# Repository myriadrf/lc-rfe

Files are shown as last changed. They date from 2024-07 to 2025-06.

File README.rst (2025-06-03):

LibreCellular RF Front-End
==========================

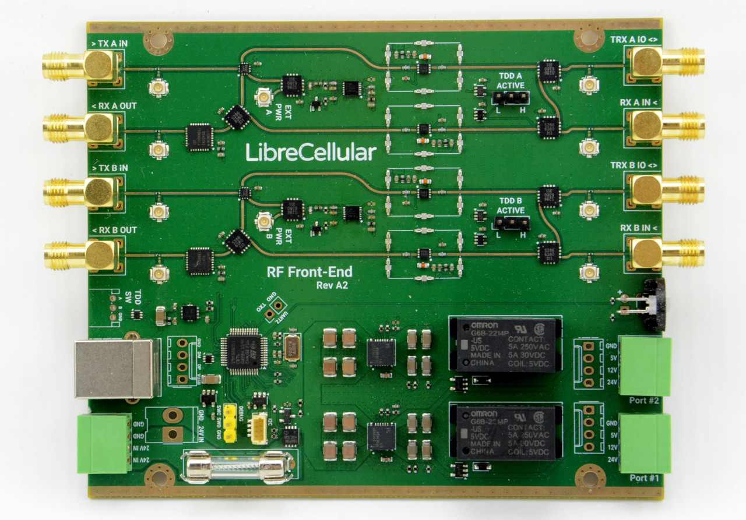
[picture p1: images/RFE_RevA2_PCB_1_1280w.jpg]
LibreCellular RFE PCBA.


This repository contains the PCB (KiCAD) design for the RF Front-End (RFE).

For further details see the `LibreCellular Documentation`_.

Licence
-------

LibreCelluar RF Front-End is copyright 2024, 2025 Ordinatra Minima Ltd & AB Open Ltd, and provided under the Solderpad Hardware License v2.1.

.. _LibreCellular Documentation: https://librecellular.org/developer/hardware/rf/rfe.html

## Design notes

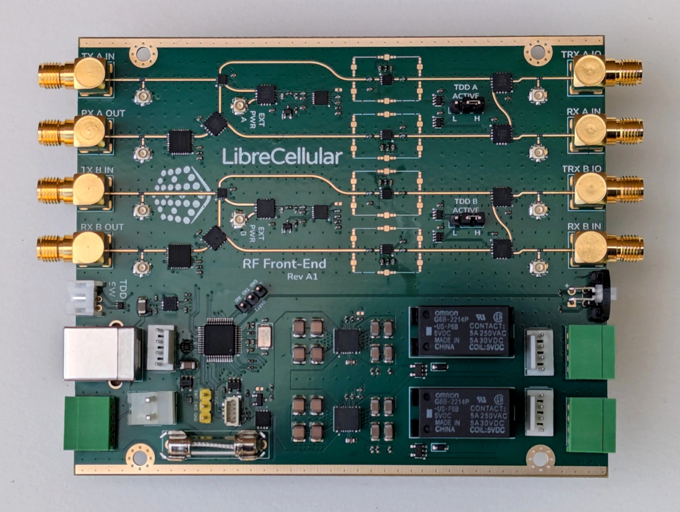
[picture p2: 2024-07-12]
images/RFE_RevA1_PCB_1_1280w.jpg

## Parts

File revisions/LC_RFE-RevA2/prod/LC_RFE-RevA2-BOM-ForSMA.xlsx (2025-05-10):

RefDes | Value | JLCASSY | Footprint
C1106,C1206,C1306,C1406 | 1000p | C1523 | Capacitor_SMD:C_0402_1005Metric
C305,C306 | 18p | C1549 | Capacitor_SMD:C_0402_1005Metric
C1104,C1204,C1304,C1404 | 27p | C1557 | Capacitor_SMD:C_0402_1005Metric
C216 | 8.2p | C1579 | Capacitor_SMD:C_0402_1005Metric
IC1504,IC1604 | SN74LVC1G32DCK | C7840 | Package_TO_SOT_SMD:SOT-353_SC-70-5
IC1503,IC1603 | SN74LVC1G04DCK | C8207 | Package_TO_SOT_SMD:SOT-353_SC-70-5
D102,D501 | USBLC6-2P6 | C15999 | LC_RFE:SOT-666
C301,C308,C603,C701,C801,C902,C1002,C1101,C1201,C1301,C1401 | 4u7 | C23733 | Capacitor_SMD:C_0402_1005Metric
R303 | 2.2K | C25879 | Resistor_SMD:R_0402_1005Metric
R304,R305 | 3.3K | C25890 | Resistor_SMD:R_0402_1005Metric
R204 | 6.98K 1% | C47500 | Resistor_SMD:R_0402_1005Metric
C1102,C1202,C1302,C1402 | 1u | C52923 | Capacitor_SMD:C_0402_1005Metric
C1103,C1203,C1303,C1403 | 100p | C77177 | Capacitor_SMD:C_0402_1005Metric
D101 | BZX84C12LT1G | C82475 | Package_TO_SOT_SMD:SOT-23
C908,C1008 | 1.8p | C85878 | Capacitor_SMD:C_0402_1005Metric
R501,R503,R505,R507,R509,R511,R513,R515 | 0 | C106227 | LC_RFE:0201-SQUARE
C906,C907,C1006,C1007 | 1n | C126493 | Capacitor_SMD:C_0402_1005Metric
D401,D402 | D_Schottky | C191023 | Diode_SMD:D_SOD-323_HandSoldering
IC401,IC402 | RT9742CGJ5 | C250546 | Package_TO_SOT_SMD:TSOT-23-5
R208 | 12.1K | C281773 | Resistor_SMD:R_0402_1005Metric
C302,C303,C304,C309,C602,C604,C702,C802,C903,C904,C905,C910,C911,C912,C1003,C1004,C1005,C1010,C1011,C1012,C1105,C1205,C1305,C1405,C1501,C1502,C1503,C1504,C1601,C1602,C1603,C1604 | 100n | C307331 | Capacitor_SMD:C_0402_1005Metric
R902,R1002 | 68 0.1% | C317908 | Resistor_SMD:R_0402_1005Metric
R105 | 75K 0.1% | C319479 | Resistor_SMD:R_0402_1005Metric
Q101 | BSZ086P03NS3G | C459171 | LC_RFE:TSDSON-8(3.3x3.3)
IC601 | Power-LDO_NCP59800BMNADJTBG | C464053 | LC_RFE:DFN-8(3x3)
C207,C208,C209,C210,C217,C218,C219,C220,C307,C601 | 22u | C478862 | Capacitor_SMD:C_1206_3216Metric
L601,L701,L801,L901,L1001,L1101,L1201,L1301,L1401 | FB | C491491 | Inductor_SMD:L_0402_1005Metric
IC302 | TPS7A0533PDBV | C493453 | Package_TO_SOT_SMD:SOT-23-5
R201 | 110K 0.1% | C517659 | Resistor_SMD:R_0402_1005Metric
C205,C215 | 1u | C519560 | Capacitor_SMD:C_0603_1608Metric
C201,C202,C203,C204,C211,C212,C213,C214 | 10u | C597578 | Capacitor_SMD:C_1210_3225Metric
IC902,IC1002 | Power-VRef_ADR5040BKSZ-REEL7 | C659592 | SOT65P210X110-3N
IC901,IC1001 | RF-PwrDet_LTC5587IDD#TRPBF | C688698 | LC_RFE:SON45P300X300X80-13N-D
R104,R106,R107,R108 | 26.1K 0.1% | C728557 | Resistor_SMD:R_0402_1005Metric
R601 | 30K9 | C852715 | Resistor_SMD:R_0402_1005Metric
R205 | 40.2K 0.1% | C852775 | Resistor_SMD:R_0402_1005Metric
IC701,IC801 | RF-Attenuator_F1956NBGI8 | C1511898 | LC_RFE:QFN50P500X500X80-33N-D
IC904,IC1004 | RF-Switch-SP3T_SKY13588-460LF | C2151906 | LC_RFE:QFN50P200X200X65-13N-D
R103 | 191K 0.1% | C2441163 | Resistor_SMD:R_0402_1005Metric
IC301 | STM32G0B1CBTx | C2847904 | Package_QFP:LQFP-48_7x7mm_P0.5mm
CON509,CON510,CON511,CON512,CON513,CON514,CON515,CON516,CON901,CON1001 | uFL | C2894919 | LC_RFE:Molex_734120110
R102,R202,R203,R206,R207,R301,R306,R401,R402,R602 | 10K | C2902636 | Resistor_SMD:R_0402_1005Metric
R302,R901,R1001 | 390 | C2906937 | Resistor_SMD:R_0402_1005Metric
Y301 | 8MHz | C3035202 | LC_RFE:Crystal_SMD_5032-2Pin_5.0x3.2mm
IC903,IC905,IC1003,IC1005 | RF-Switch-SPDT_SKY13286-359LF | C3304168 | LC_RFE:QFN65P400X400X100-17N-D
IC1501,IC1502,IC1601,IC1602 | RF-Switch_SKY13286-359LF | C3304168 | LC_RFE:QFN65P400X400X100-17N-D
L902,L1002 | 1.5nH | C3911113 | Inductor_SMD:L_0402_1005Metric
IC201,IC202 | Power-Buck_TPSM63604RDLR | C5219289 | LC_RFE:B3QFN-20(5.0x5.5)-RDL0020A
IC303 | FT24C32A-ELR-T | C5263776 | Package_TO_SOT_SMD:SOT-23-5
IC1101,IC1201,IC1301,IC1401 | RF-LNA_TQL9063 | C5346221 | LC_RFE:SON50P200X200X90-9N
L1102,L1202,L1302,L1402 | 68nH | C19191685 | Inductor_SMD:L_0603_1608Metric
MECH1101_A1, MECH1101_B1, MECH1101_C1, MECH1101_D1, MECH1101_E1, MECH1101_F1, MECH1201_A1, MECH1201_B1, MECH1201_C1, MECH1201_D1, MECH1201_E1, MECH1201_F1, MECH1301_A1, MECH1301_B1, MECH1301_C1, MECH1301_D1, MECH1301_E1, MECH1301_F1, MECH1401_A1, MECH1401_B1, MECH1401_C1, MECH1401_D1, MECH1401_E1, MECH1401_F1 | Harwin_S0941-46R | C3308740 | Harwin_S0941-46R
CON105 | BM04B-SRSS-TB | C160390 | BM04B-SRSS-TB

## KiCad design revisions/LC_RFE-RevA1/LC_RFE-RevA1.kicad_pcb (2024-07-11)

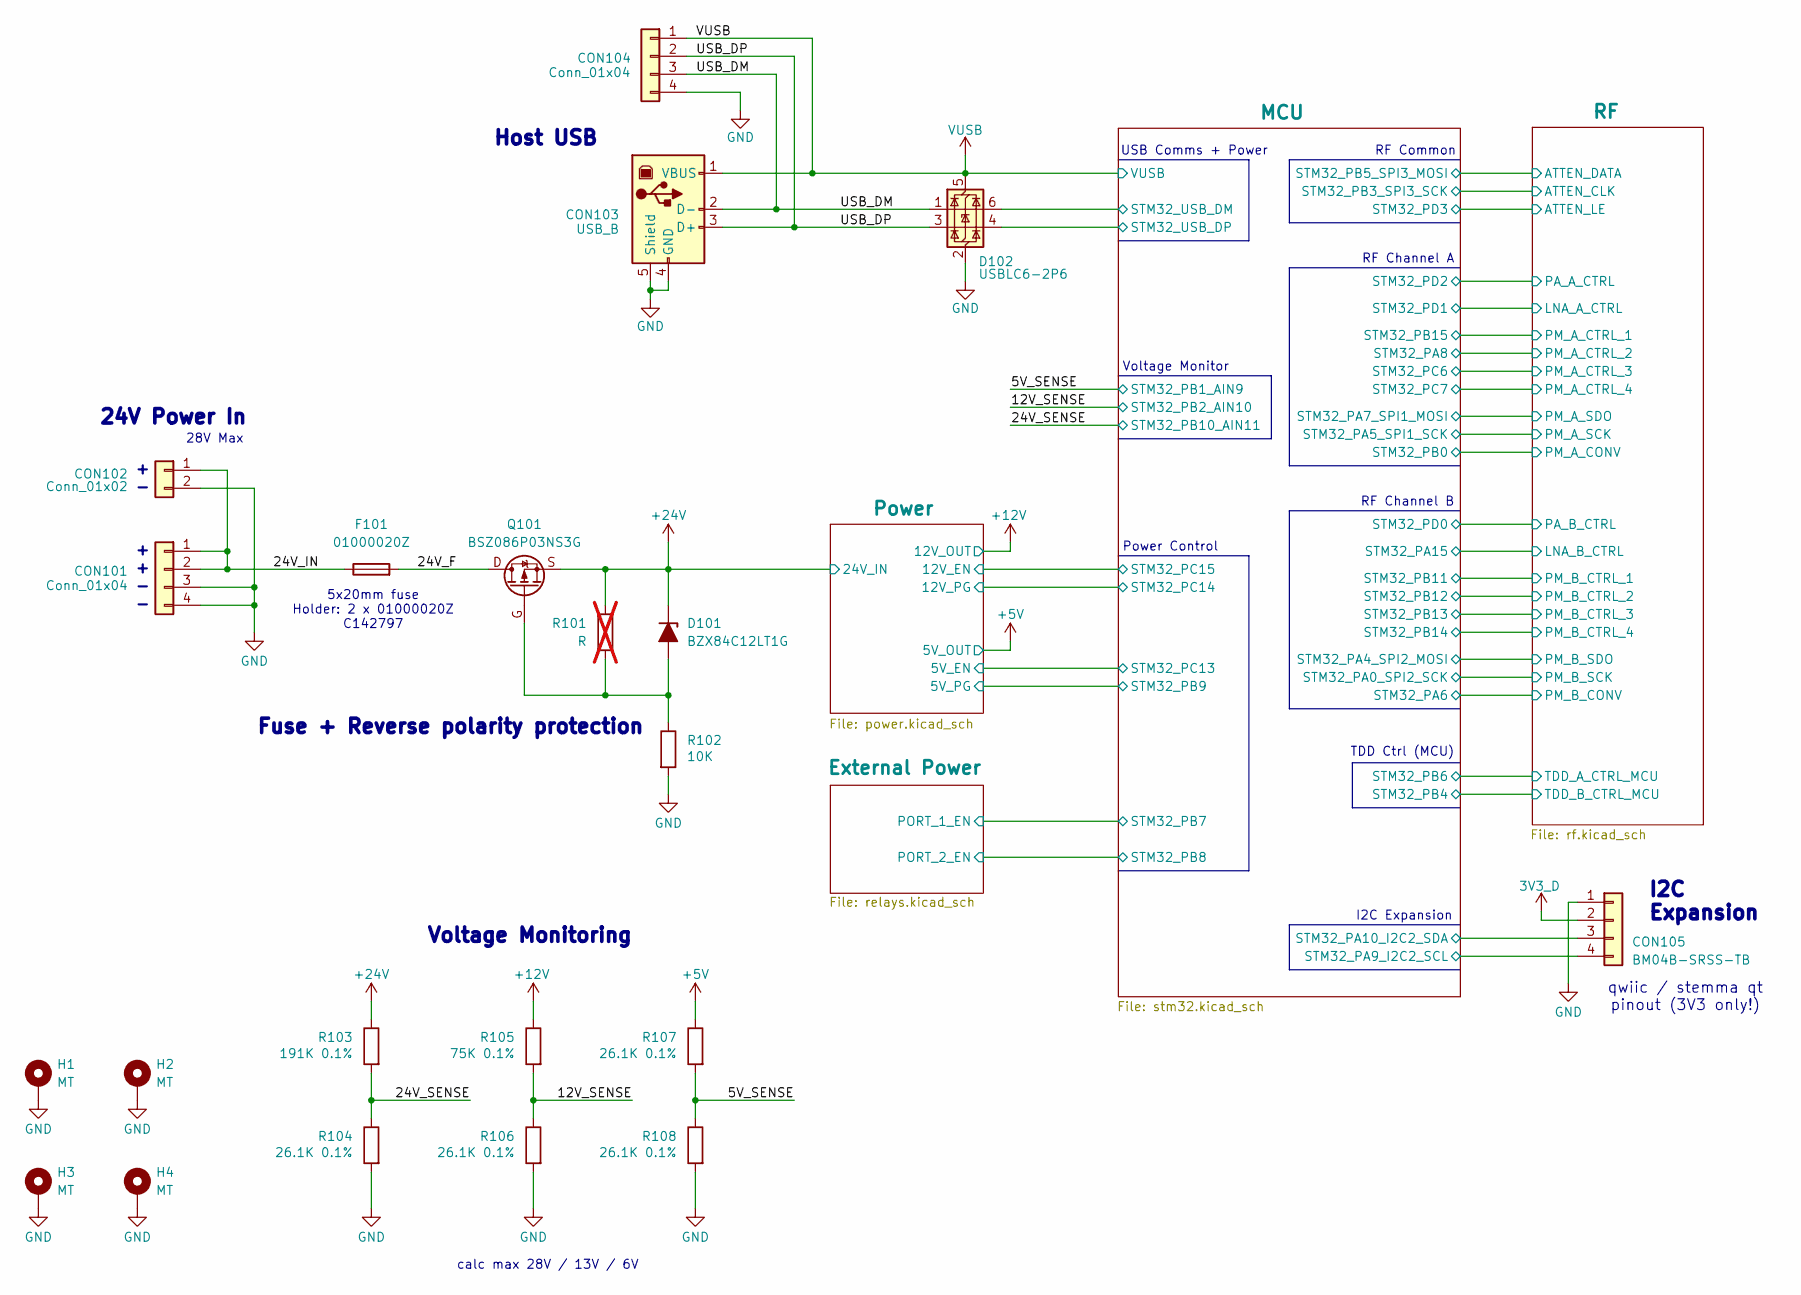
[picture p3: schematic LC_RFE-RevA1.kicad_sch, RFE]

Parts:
CON101: Conn_01x04; Dorabo_DB2ERC-2.5-4P-GN
CON102: Conn_01x02; Molex_KK-396_5273-02A_1x02_P3.96mm_Vertical
CON103: USB_B; Samtec_USBR-B-S-F-O-TH
CON104: Conn_01x04; Molex_KK-254_AE-6410-04A_1x04_P2.54mm_Vertical
CON105: BM04B-SRSS-TB
D101: BZX84C12LT1G; SOT-23; JLCASSY C82475
D102: USBLC6-2P6; SOT-666; JLCASSY C15999
F101: 01000020Z; Fuseholder_2x_Littelfuse_100_series_5x20mm; JLCASSY C142797
H1, H2, H3, H4: MT; MountingHole_3.2mm_M3_Pad_Via
Q101: BSZ086P03NS3G; TSDSON-8(3.3x3.3); JLCASSY C459171
R101: R; R_0402_1005Metric; not fitted
R102: 10K; R_0402_1005Metric; JLCASSY C2902636
R103: 191K 0.1%; R_0402_1005Metric; JLCASSY C2441163
R104, R106, R107, R108: 26.1K 0.1%; R_0402_1005Metric; JLCASSY C728557
R105: 75K 0.1%; R_0402_1005Metric; JLCASSY C319479

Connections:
3V3_D: CON105.2; also elsewhere on the board
+5V: R107.1; also elsewhere on the board
+12V: R105.1; also elsewhere on the board
+24V: D101.3 (K), Q101.S, R101.1, R103.1; also elsewhere on the board
/5V_SENSE: R107.2, R108.1; also elsewhere on the board
/12V_SENSE: R105.2, R106.1; also elsewhere on the board
/24V_F: F101.2, Q101.D
/24V_IN: CON101.1, CON101.2, CON102.1, F101.1
/24V_SENSE: R103.2, R104.1; also elsewhere on the board
/MCU/SCL: CON105.4; also elsewhere on the board
/MCU/SDA: CON105.3; also elsewhere on the board
/MCU/STM32_USB_DM: D102.6 (I/O1); also elsewhere on the board
/MCU/STM32_USB_DP: D102.4 (I/O2); also elsewhere on the board
/USB_DM: CON103.2 (D-), CON104.3, D102.1 (I/O1)
/USB_DP: CON103.3 (D+), CON104.2, D102.3 (I/O2)
GND: CON101.3, CON101.4, CON102.2, CON103.4 (GND), CON103.5 (Shield), CON104.4, CON105.1, D102.2 (GND), H1.1, H2.1, H3.1, H4.1, R102.2, R104.2, R106.2, R108.2; also elsewhere on the board
unnamed: D101.1 (A), Q101.G, R101.2, R102.1
VUSB: CON103.1 (VBUS), CON104.1, D102.5 (VBUS); also elsewhere on the board

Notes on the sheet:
5x20mm fuse Holder: 2 x 01000020Z C142797
I2C Expansion
Voltage Monitor
28V Max
calc max 28V / 13V / 6V
TDD Ctrl (MCU)
qwiic / stemma qt pinout (3V3 only!)
RF Common
Power Control
Voltage Monitoring
24V Power In
Host USB
RF Channel B
I2C Expansion
USB Comms + Power
Fuse + Reverse polarity protection
RF Channel A

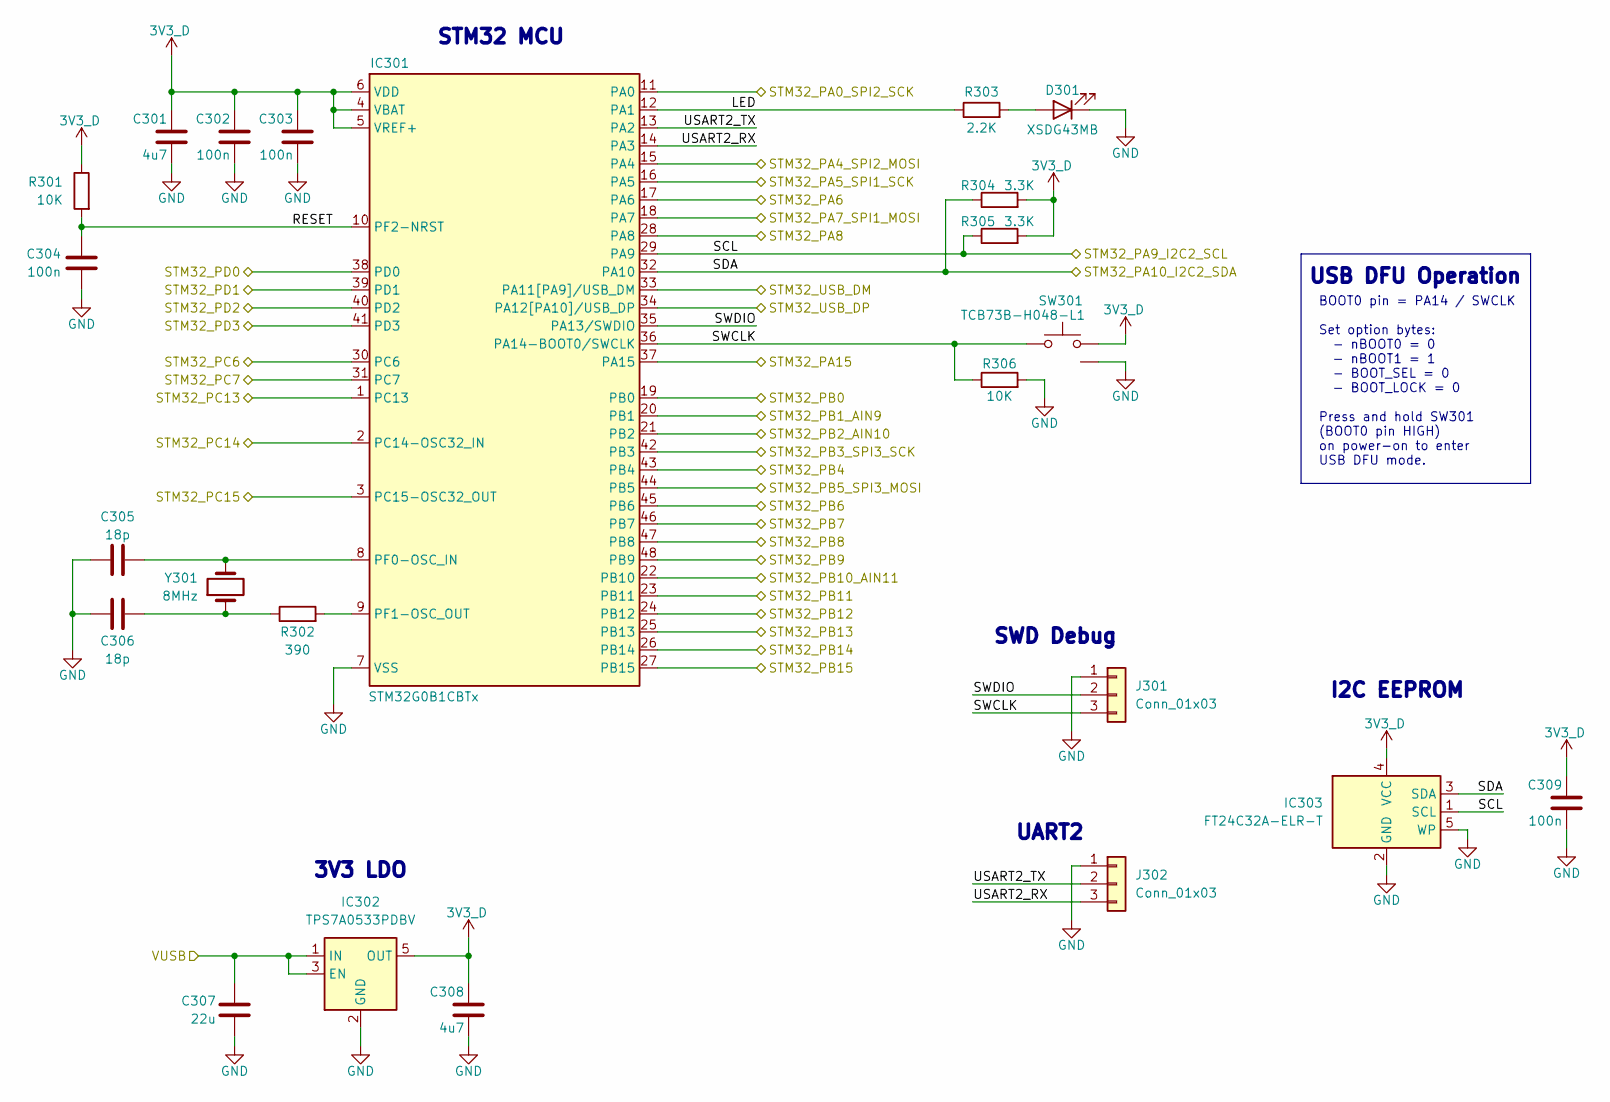
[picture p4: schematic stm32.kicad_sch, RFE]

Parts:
C301, C308: 4u7; C_0402_1005Metric; JLCASSY C23733
C302, C303, C304, C309: 100n; C_0402_1005Metric; JLCASSY C307331
C305, C306: 18p; C_0402_1005Metric; JLCASSY C1549
C307: 22u; C_1206_3216Metric; JLCASSY C478862
D301: XSDG43MB; LED_D3.0mm_Horizontal_O3.81mm_Z6.0mm; DIGIKEY 1497-1043-ND
IC301: STM32G0B1CBTx; LQFP-48_7x7mm_P0.5mm; JLCASSY C2847904
IC302: TPS7A0533PDBV; SOT-23-5; JLCASSY C493453
IC303: FT24C32A-ELR-T; SOT-23-5; JLCASSY C5263776
J301, J302: Conn_01x03; PinHeader_1x03_P2.54mm_Vertical
R301, R306: 10K; R_0402_1005Metric; JLCASSY C2902636
R302: 390; R_0402_1005Metric; JLCASSY C2906937
R303: 2.2K; R_0402_1005Metric; JLCASSY C25879
R304, R305: 3.3K; R_0402_1005Metric; JLCASSY C25890
SW301: TCB73B-H048-L1; PushButton-TCB73B-H048-L1; JLCASSY C2890354
Y301: 8MHz; Crystal_SMD_5032-2Pin_5.0x3.2mm; JLCASSY C3035202

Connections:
3V3_D: C301.1, C302.1, C303.1, C308.1, C309.1, IC301.4 (VBAT), IC301.5 (VREF+), IC301.6 (VDD), IC302.5 (OUT), IC303.4 (VCC), R301.1, R304.2, R305.2, SW301.2; also elsewhere on the board
/5V_SENSE: IC301.20 (PB1); also elsewhere on the board
/12V_SENSE: IC301.21 (PB2); also elsewhere on the board
/24V_SENSE: IC301.22 (PB10); also elsewhere on the board
/External Power/PORT_1_EN: IC301.46 (PB7); also elsewhere on the board
/External Power/PORT_2_EN: IC301.47 (PB8); also elsewhere on the board
/MCU/LED: IC301.12 (PA1), R303.1
/MCU/RESET: C304.1, IC301.10 (PF2-NRST), R301.2
/MCU/SCL: IC301.29 (PA9), IC303.1 (SCL), R305.1; also elsewhere on the board
/MCU/SDA: IC301.32 (PA10), IC303.3 (SDA), R304.1; also elsewhere on the board
/MCU/STM32_PA0_SPI2_SCK: IC301.11 (PA0); also elsewhere on the board
/MCU/STM32_PA4_SPI2_MOSI: IC301.15 (PA4); also elsewhere on the board
/MCU/STM32_PA5_SPI1_SCK: IC301.16 (PA5); also elsewhere on the board
/MCU/STM32_PA6: IC301.17 (PA6); also elsewhere on the board
/MCU/STM32_PA7_SPI1_MOSI: IC301.18 (PA7); also elsewhere on the board
/MCU/STM32_PA8: IC301.28 (PA8); also elsewhere on the board
/MCU/STM32_PA15: IC301.37 (PA15); also elsewhere on the board
/MCU/STM32_PB0: IC301.19 (PB0); also elsewhere on the board
/MCU/STM32_PB3_SPI3_SCK: IC301.42 (PB3); also elsewhere on the board
/MCU/STM32_PB4: IC301.43 (PB4); also elsewhere on the board
/MCU/STM32_PB5_SPI3_MOSI: IC301.44 (PB5); also elsewhere on the board
/MCU/STM32_PB6: IC301.45 (PB6); also elsewhere on the board
/MCU/STM32_PB9: IC301.48 (PB9); also elsewhere on the board
/MCU/STM32_PB11: IC301.23 (PB11); also elsewhere on the board
/MCU/STM32_PB12: IC301.24 (PB12); also elsewhere on the board
/MCU/STM32_PB13: IC301.25 (PB13); also elsewhere on the board
/MCU/STM32_PB14: IC301.26 (PB14); also elsewhere on the board
/MCU/STM32_PB15: IC301.27 (PB15); also elsewhere on the board
/MCU/STM32_PC6: IC301.30 (PC6); also elsewhere on the board
/MCU/STM32_PC7: IC301.31 (PC7); also elsewhere on the board
/MCU/STM32_PC13: IC301.1 (PC13); also elsewhere on the board
/MCU/STM32_PC14: IC301.2 (PC14-OSC32_IN); also elsewhere on the board
/MCU/STM32_PC15: IC301.3 (PC15-OSC32_OUT); also elsewhere on the board
/MCU/STM32_PD0: IC301.38 (PD0); also elsewhere on the board
/MCU/STM32_PD1: IC301.39 (PD1); also elsewhere on the board
/MCU/STM32_PD2: IC301.40 (PD2); also elsewhere on the board
/MCU/STM32_PD3: IC301.41 (PD3); also elsewhere on the board
/MCU/STM32_USB_DM: IC301.33 (PA11[PA9]/USB_DM); also elsewhere on the board
/MCU/STM32_USB_DP: IC301.34 (PA12[PA10]/USB_DP); also elsewhere on the board
/MCU/SWCLK: IC301.36 (PA14-BOOT0/SWCLK), J301.3, R306.1, SW301.1
/MCU/SWDIO: IC301.35 (PA13/SWDIO), J301.2
/MCU/USART2_RX: IC301.14 (PA3), J302.3
/MCU/USART2_TX: IC301.13 (PA2), J302.2
GND: C301.2, C302.2, C303.2, C304.2, C305.1, C306.1, C307.2, C308.2, C309.2, D301.1 (K), IC301.7 (VSS), IC302.2 (GND), IC303.2 (GND), IC303.5 (WP), J301.1, J302.1, R306.2, SW301.3; also elsewhere on the board
unnamed: C306.2, R302.1, Y301.1
unnamed: D301.2 (A), R303.2
unnamed: C305.2, IC301.8 (PF0-OSC_IN), Y301.2
unnamed: IC301.9 (PF1-OSC_OUT), R302.2
VUSB: C307.1, IC302.1 (IN), IC302.3 (EN); also elsewhere on the board

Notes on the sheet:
I2C EEPROM
3V3 LDO
BOOT0 pin = PA14 / SWCLK Set option bytes: - nBOOT0 = 0 - nBOOT1 = 1 - BOOT_SEL = 0 - BOOT_LOCK = 0 Press and hold SW301 (BOOT0 pin HIGH) on power-on to enter USB DFU mode.
UART2
SWD Debug
USB DFU Operation
STM32 MCU

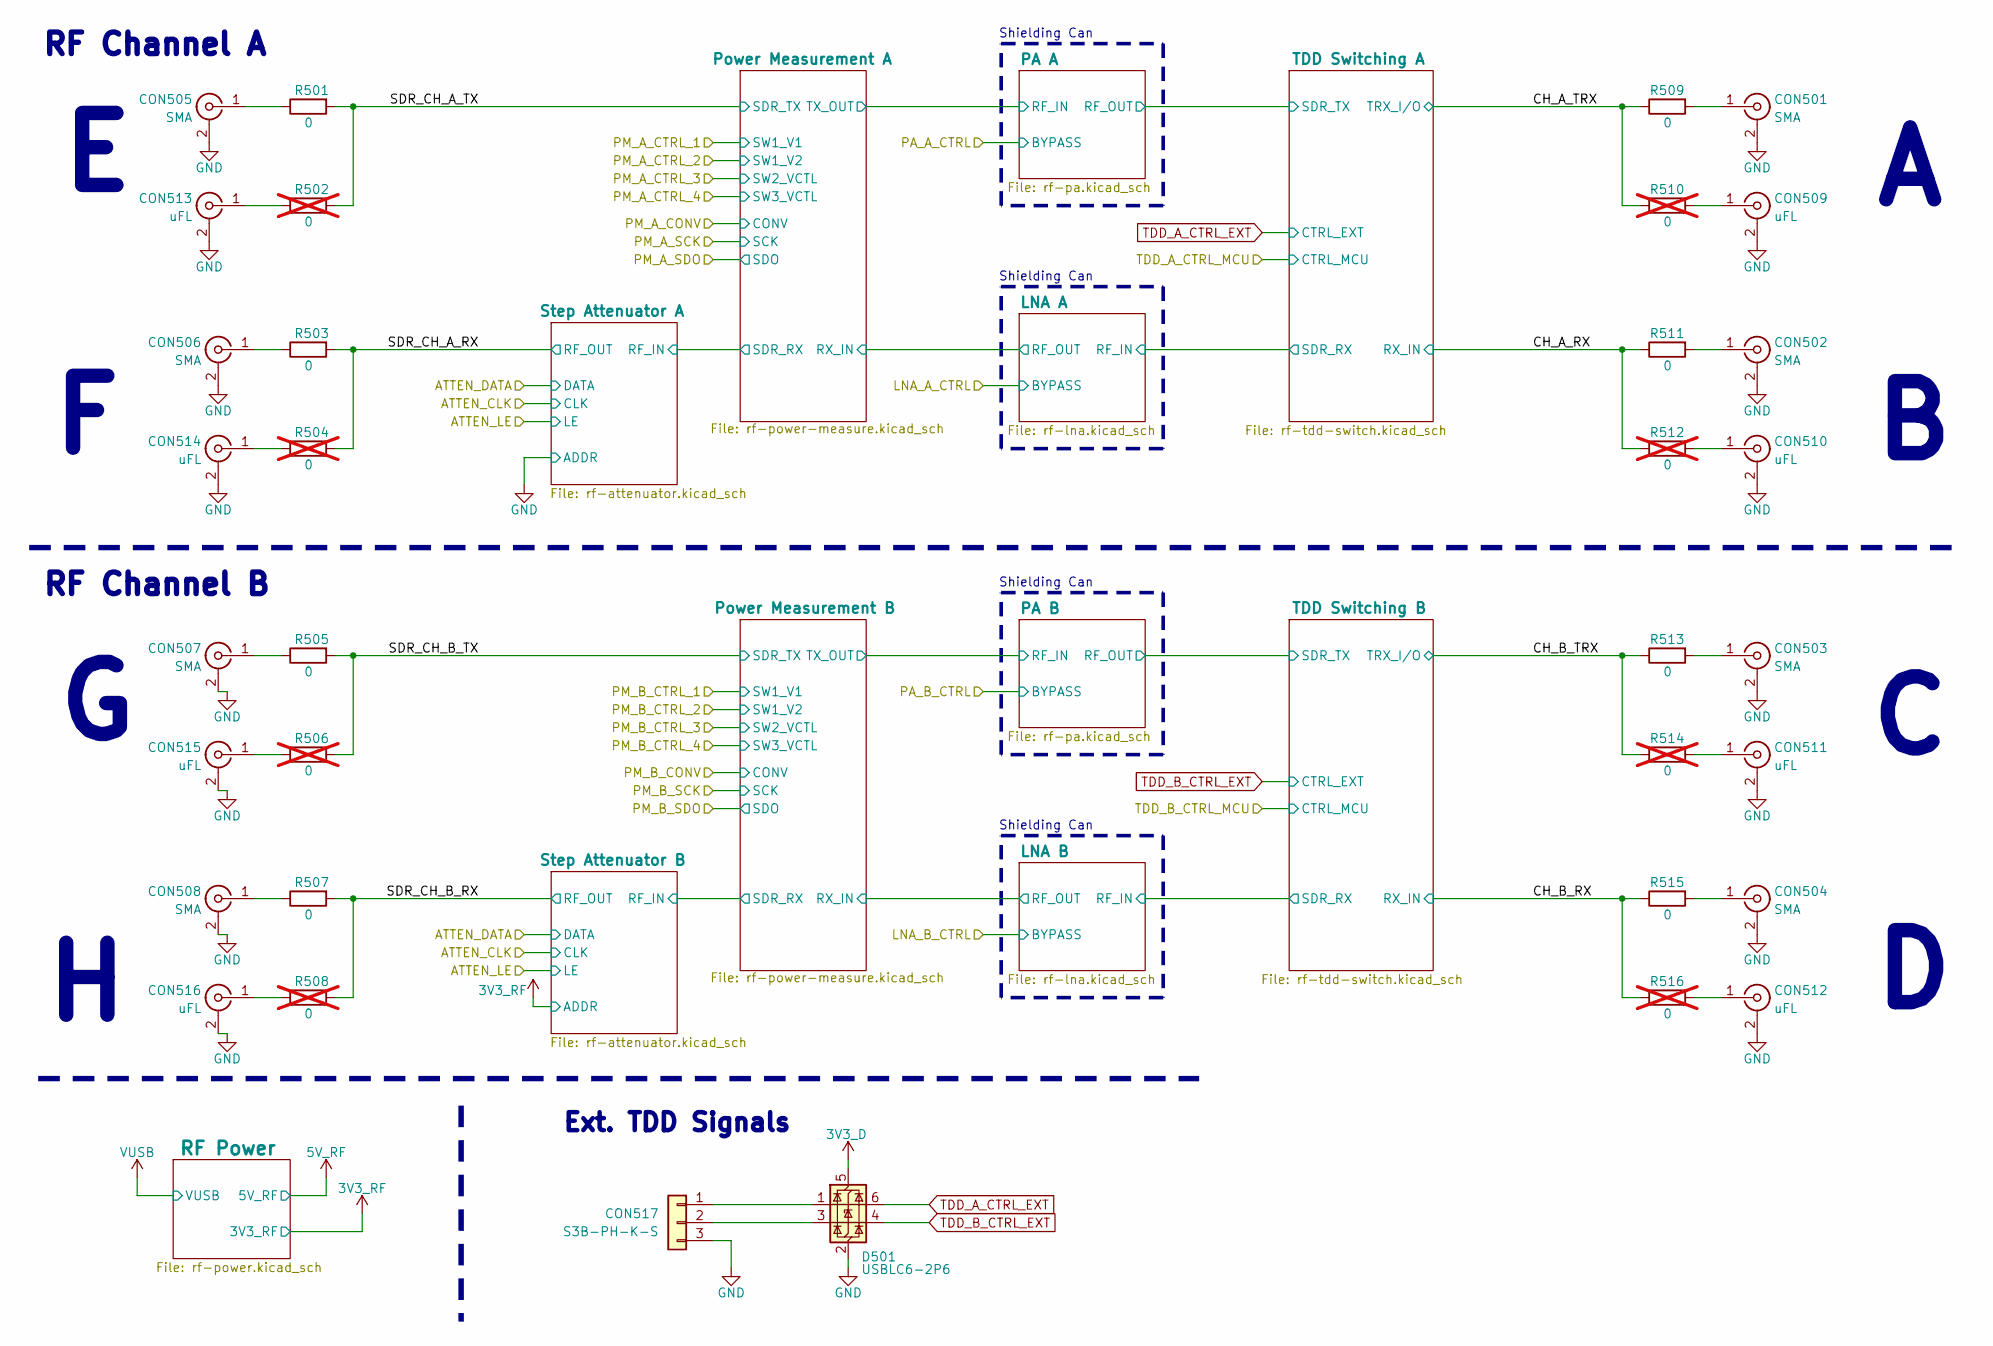
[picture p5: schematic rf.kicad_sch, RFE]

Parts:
CON501, CON502, CON503, CON504, CON505, CON506, CON507, CON508: SMA; Samtec_SMA-J-P-H-RA-TH1
CON509, CON510, CON511, CON512, CON513, CON514, CON515, CON516: uFL; Molex_734120110; MPN HC-RF-IPEX0303-01; JLCASSY C2894919
CON517: S3B-PH-K-S; Connector-2mm-1x3P_S3B-PH-K-S
D501: USBLC6-2P6; SOT-666; JLCASSY C15999
R501, R503, R505, R507, R509, R511, R513, R515: 0; 0201-SQUARE; MPN RC0201FR-070RL; JLCASSY C106227
R502, R504, R506, R508, R510, R512, R514, R516: 0; 0201-SQUARE; MPN RC0201FR-070RL; JLCASSY C106227; not fitted

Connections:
3V3_D: D501.5 (VBUS); also elsewhere on the board
/RF/CH_A_RX: R511.1, R512.1; also elsewhere on the board
/RF/CH_A_TRX: R509.1, R510.1; also elsewhere on the board
/RF/CH_B_RX: R515.1, R516.1; also elsewhere on the board
/RF/CH_B_TRX: R513.1, R514.1; also elsewhere on the board
/RF/SDR_CH_A_RX: R503.2, R504.2; also elsewhere on the board
/RF/SDR_CH_A_TX: R501.2, R502.2; also elsewhere on the board
/RF/SDR_CH_B_RX: R507.2, R508.2; also elsewhere on the board
/RF/SDR_CH_B_TX: R505.2, R506.2; also elsewhere on the board
GND: CON501.2 (Ext), CON502.2 (Ext), CON503.2 (Ext), CON504.2 (Ext), CON505.2 (Ext), CON506.2 (Ext), CON507.2 (Ext), CON508.2 (Ext), CON509.2 (Ext), CON510.2 (Ext), CON511.2 (Ext), CON512.2 (Ext), CON513.2 (Ext), CON514.2 (Ext), CON515.2 (Ext), CON516.2 (Ext), CON517.3, D501.2 (GND); also elsewhere on the board
unnamed: CON501.1 (In), R509.2
unnamed: CON502.1 (In), R511.2
unnamed: CON503.1 (In), R513.2
unnamed: CON504.1 (In), R515.2
unnamed: CON505.1 (In), R501.1
unnamed: CON506.1 (In), R503.1
unnamed: CON507.1 (In), R505.1
unnamed: CON508.1 (In), R507.1
unnamed: CON509.1 (In), R510.2
unnamed: CON510.1 (In), R512.2
unnamed: CON511.1 (In), R514.2
unnamed: CON512.1 (In), R516.2
unnamed: CON513.1 (In), R502.1
unnamed: CON514.1 (In), R504.1
unnamed: CON515.1 (In), R506.1
unnamed: CON516.1 (In), R508.1
unnamed: CON517.1, D501.1 (I/O1)
unnamed: CON517.2, D501.3 (I/O2)
TDD_A_CTRL_EXT: D501.6 (I/O1); also elsewhere on the board
TDD_B_CTRL_EXT: D501.4 (I/O2); also elsewhere on the board

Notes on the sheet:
Ext. TDD Signals
Shielding Can
RF Channel B
RF Channel A

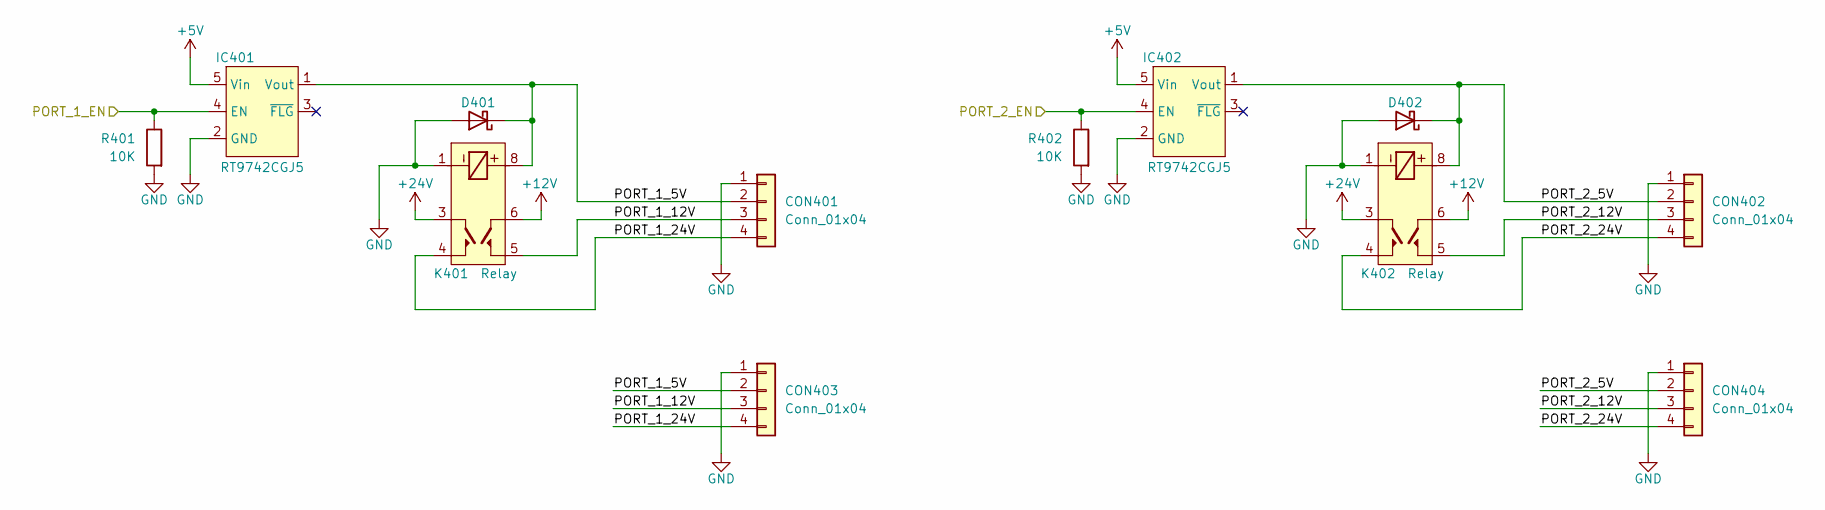
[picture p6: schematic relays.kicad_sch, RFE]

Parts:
CON401, CON402: Conn_01x04; Dorabo_DB2ERC-2.5-4P-GN
CON403, CON404: Conn_01x04; Molex_KK-254_AE-6410-04A_1x04_P2.54mm_Vertical
D401, D402: D_Schottky; D_SOD-323_HandSoldering; JLCASSY C191023
IC401, IC402: RT9742CGJ5; TSOT-23-5; JLCASSY C250546
K401, K402: Relay; Omron_P6B-26P+G6B-2214
R401, R402: 10K; R_0402_1005Metric; JLCASSY C2902636

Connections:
+5V: IC401.5 (Vin), IC402.5 (Vin); also elsewhere on the board
+12V: K401.6, K402.6; also elsewhere on the board
+24V: K401.3, K402.3; also elsewhere on the board
/External Power/PORT_1_5V: CON401.2, CON403.2, D401.1 (K), IC401.1 (Vout), K401.8
/External Power/PORT_1_12V: CON401.3, CON403.3, K401.5
/External Power/PORT_1_24V: CON401.4, CON403.4, K401.4
/External Power/PORT_1_EN: IC401.4 (EN), R401.1; also elsewhere on the board
/External Power/PORT_2_5V: CON402.2, CON404.2, D402.1 (K), IC402.1 (Vout), K402.8
/External Power/PORT_2_12V: CON402.3, CON404.3, K402.5
/External Power/PORT_2_24V: CON402.4, CON404.4, K402.4
/External Power/PORT_2_EN: IC402.4 (EN), R402.1; also elsewhere on the board
GND: CON401.1, CON402.1, CON403.1, CON404.1, D401.2 (A), D402.2 (A), IC401.2 (GND), IC402.2 (GND), K401.1, K402.1, R401.2, R402.2; also elsewhere on the board

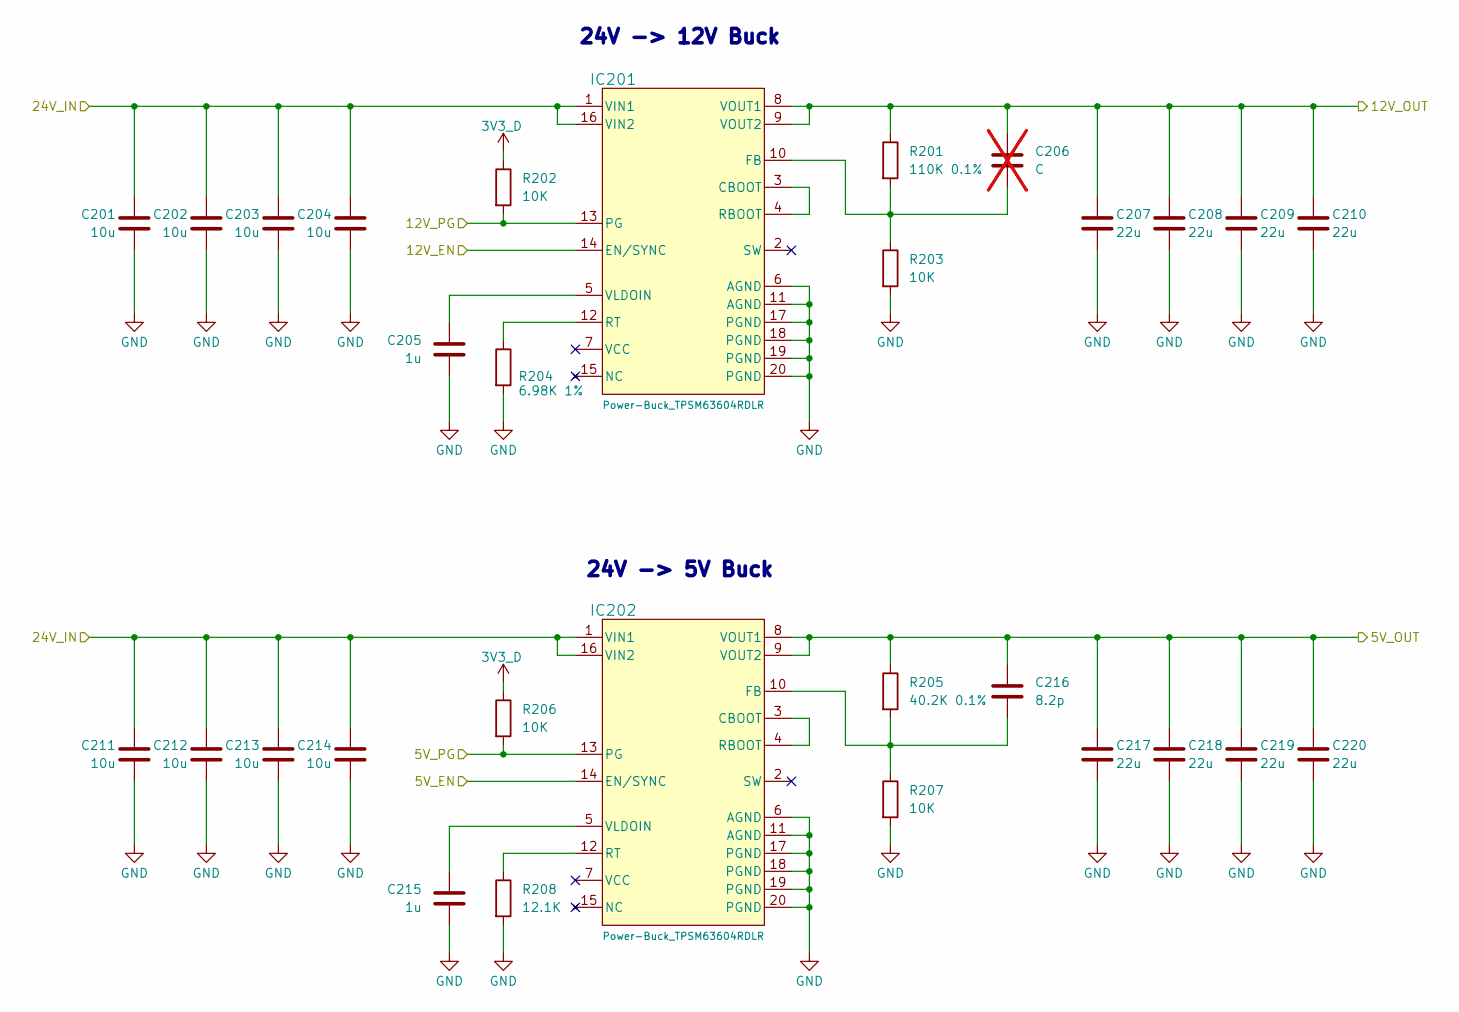
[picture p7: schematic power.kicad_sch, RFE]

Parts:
C201, C202, C203, C204, C211, C212, C213, C214: 10u; C_1210_3225Metric; JLCASSY C597578
C205, C215: 1u; C_0603_1608Metric; JLCASSY C519560
C206: C; C_0402_1005Metric; not fitted
C207, C208, C209, C210, C217, C218, C219, C220: 22u; C_1206_3216Metric; JLCASSY C478862
C216: 8.2p; C_0402_1005Metric; JLCASSY C1579
IC201, IC202: Power-Buck_TPSM63604RDLR; B3QFN-20(5.0x5.5)-RDL0020A; JLCASSY C5219289
R201: 110K 0.1%; R_0402_1005Metric; JLCASSY C517659
R202, R203, R206, R207: 10K; R_0402_1005Metric; JLCASSY C2902636
R204: 6.98K 1%; R_0402_1005Metric; JLCASSY C47500
R205: 40.2K 0.1%; R_0402_1005Metric; JLCASSY C852775
R208: 12.1K; R_0402_1005Metric; JLCASSY C281773

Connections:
3V3_D: R202.1, R206.1; also elsewhere on the board
+5V: C216.1, C217.1, C218.1, C219.1, C220.1, IC202.8 (VOUT1), IC202.9 (VOUT2), R205.1; also elsewhere on the board
+12V: C206.1, C207.1, C208.1, C209.1, C210.1, IC201.8 (VOUT1), IC201.9 (VOUT2), R201.1; also elsewhere on the board
+24V: C201.1, C202.1, C203.1, C204.1, C211.1, C212.1, C213.1, C214.1, IC201.1 (VIN1), IC201.16 (VIN2), IC202.1 (VIN1), IC202.16 (VIN2); also elsewhere on the board
/MCU/STM32_PB9: IC202.13 (PG), R206.2; also elsewhere on the board
/MCU/STM32_PC13: IC202.14 (EN/SYNC); also elsewhere on the board
/MCU/STM32_PC14: IC201.13 (PG), R202.2; also elsewhere on the board
/MCU/STM32_PC15: IC201.14 (EN/SYNC); also elsewhere on the board
GND: C201.2, C202.2, C203.2, C204.2, C205.2, C207.2, C208.2, C209.2, C210.2, C211.2, C212.2, C213.2, C214.2, C215.2, C217.2, C218.2, C219.2, C220.2, IC201.6 (AGND), IC201.11 (AGND), IC201.17 (PGND), IC201.18 (PGND), IC201.19 (PGND), IC201.20 (PGND), IC202.6 (AGND), IC202.11 (AGND), IC202.17 (PGND), IC202.18 (PGND), IC202.19 (PGND), IC202.20 (PGND), R203.2, R204.2, R207.2, R208.2; also elsewhere on the board
unnamed: IC201.3 (CBOOT), IC201.4 (RBOOT)
unnamed: C206.2, IC201.10 (FB), R201.2, R203.1
unnamed: IC201.12 (RT), R204.1
unnamed: C205.1, IC201.5 (VLDOIN)
unnamed: IC202.3 (CBOOT), IC202.4 (RBOOT)
unnamed: C216.2, IC202.10 (FB), R205.2, R207.1
unnamed: IC202.12 (RT), R208.1
unnamed: C215.1, IC202.5 (VLDOIN)

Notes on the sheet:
24V -> 5V Buck
24V -> 12V Buck

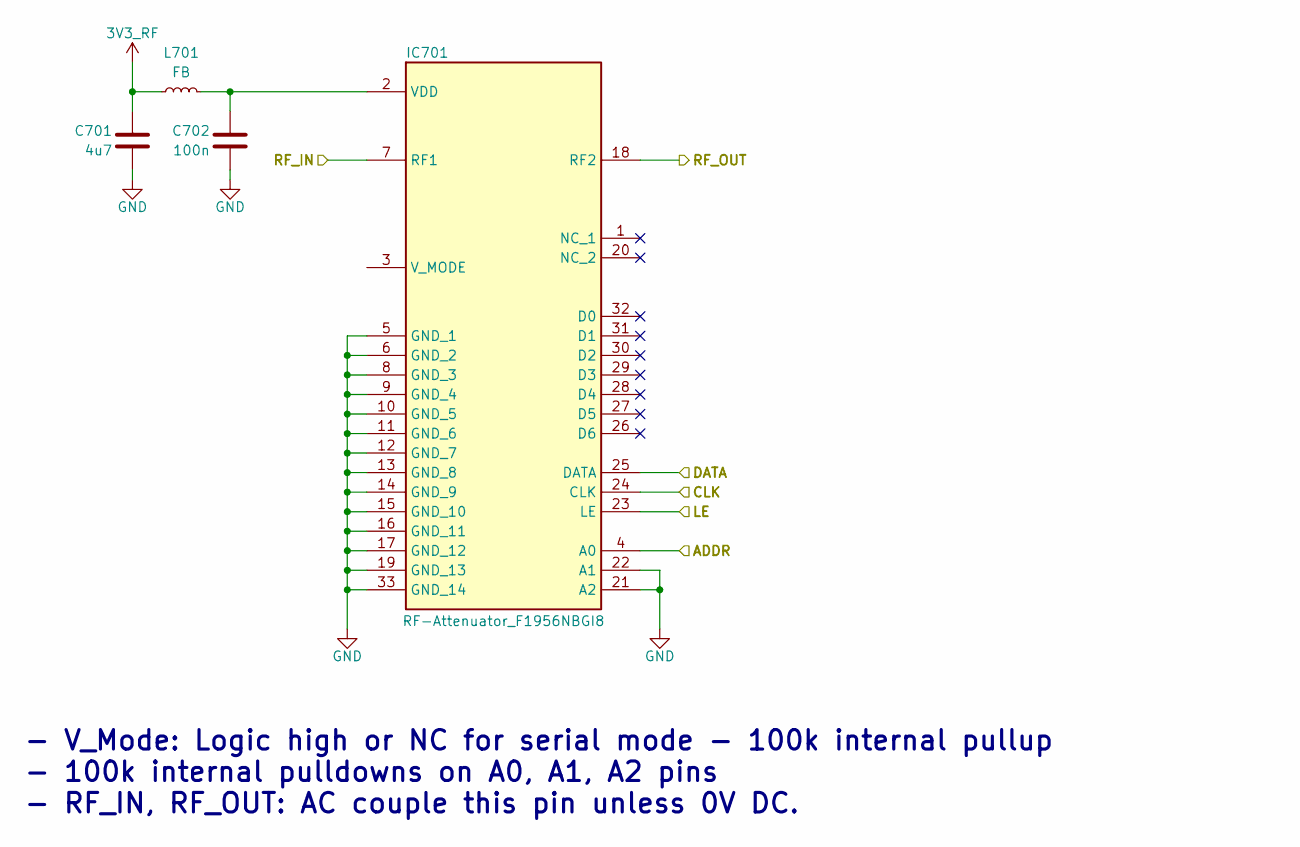
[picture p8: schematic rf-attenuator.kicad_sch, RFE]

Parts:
C701: 4u7; C_0402_1005Metric; JLCASSY C23733
C702: 100n; C_0402_1005Metric; JLCASSY C307331
IC701: RF-Attenuator_F1956NBGI8; QFN50P500X500X80-33N-D; Manufacturer_Part_Number F1956NBGI8; Mouser Part Number 972-F1956NBGI8
L701: FB; L_0402_1005Metric; JLCASSY C491491

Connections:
3V3_RF: C701.1, L701.1; also elsewhere on the board
/MCU/STM32_PB3_SPI3_SCK: IC701.24 (CLK); also elsewhere on the board
/MCU/STM32_PB5_SPI3_MOSI: IC701.25 (DATA); also elsewhere on the board
/MCU/STM32_PD3: IC701.23 (LE); also elsewhere on the board
/RF/Power Measurement A/SDR_RX: IC701.7 (RF1); also elsewhere on the board
/RF/SDR_CH_A_RX: IC701.18 (RF2); also elsewhere on the board
GND: C701.2, C702.2, IC701.4 (A0), IC701.5 (GND_1), IC701.6 (GND_2), IC701.8 (GND_3), IC701.9 (GND_4), IC701.10 (GND_5), IC701.11 (GND_6), IC701.12 (GND_7), IC701.13 (GND_8), IC701.14 (GND_9), IC701.15 (GND_10), IC701.16 (GND_11), IC701.17 (GND_12), IC701.19 (GND_13), IC701.21 (A2), IC701.22 (A1), IC701.33 (GND_14); also elsewhere on the board
unnamed: C702.1, IC701.2 (VDD), L701.2

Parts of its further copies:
C801: 4u7; C_0402_1005Metric; JLCASSY C23733
C802: 100n; C_0402_1005Metric; JLCASSY C307331
IC801: RF-Attenuator_F1956NBGI8; QFN50P500X500X80-33N-D; Manufacturer_Part_Number F1956NBGI8; Mouser Part Number 972-F1956NBGI8
L801: FB; L_0402_1005Metric; JLCASSY C491491

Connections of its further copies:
3V3_RF: C801.1, IC801.4 (A0), L801.1; also elsewhere on the board
/MCU/STM32_PB3_SPI3_SCK: IC801.24 (CLK); also elsewhere on the board
/MCU/STM32_PB5_SPI3_MOSI: IC801.25 (DATA); also elsewhere on the board
/MCU/STM32_PD3: IC801.23 (LE); also elsewhere on the board
/RF/Power Measurement B/SDR_RX: IC801.7 (RF1); also elsewhere on the board
/RF/SDR_CH_B_RX: IC801.18 (RF2); also elsewhere on the board
GND: C801.2, C802.2, IC801.5 (GND_1), IC801.6 (GND_2), IC801.8 (GND_3), IC801.9 (GND_4), IC801.10 (GND_5), IC801.11 (GND_6), IC801.12 (GND_7), IC801.13 (GND_8), IC801.14 (GND_9), IC801.15 (GND_10), IC801.16 (GND_11), IC801.17 (GND_12), IC801.19 (GND_13), IC801.21 (A2), IC801.22 (A1), IC801.33 (GND_14); also elsewhere on the board
unnamed: C802.1, IC801.2 (VDD), L801.2

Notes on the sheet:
- V_Mode: Logic high or NC for serial mode - 100k internal pullup - 100k internal pulldowns on A0, A1, A2 pins - RF_IN, RF_OUT: AC couple this pin unless 0V DC.

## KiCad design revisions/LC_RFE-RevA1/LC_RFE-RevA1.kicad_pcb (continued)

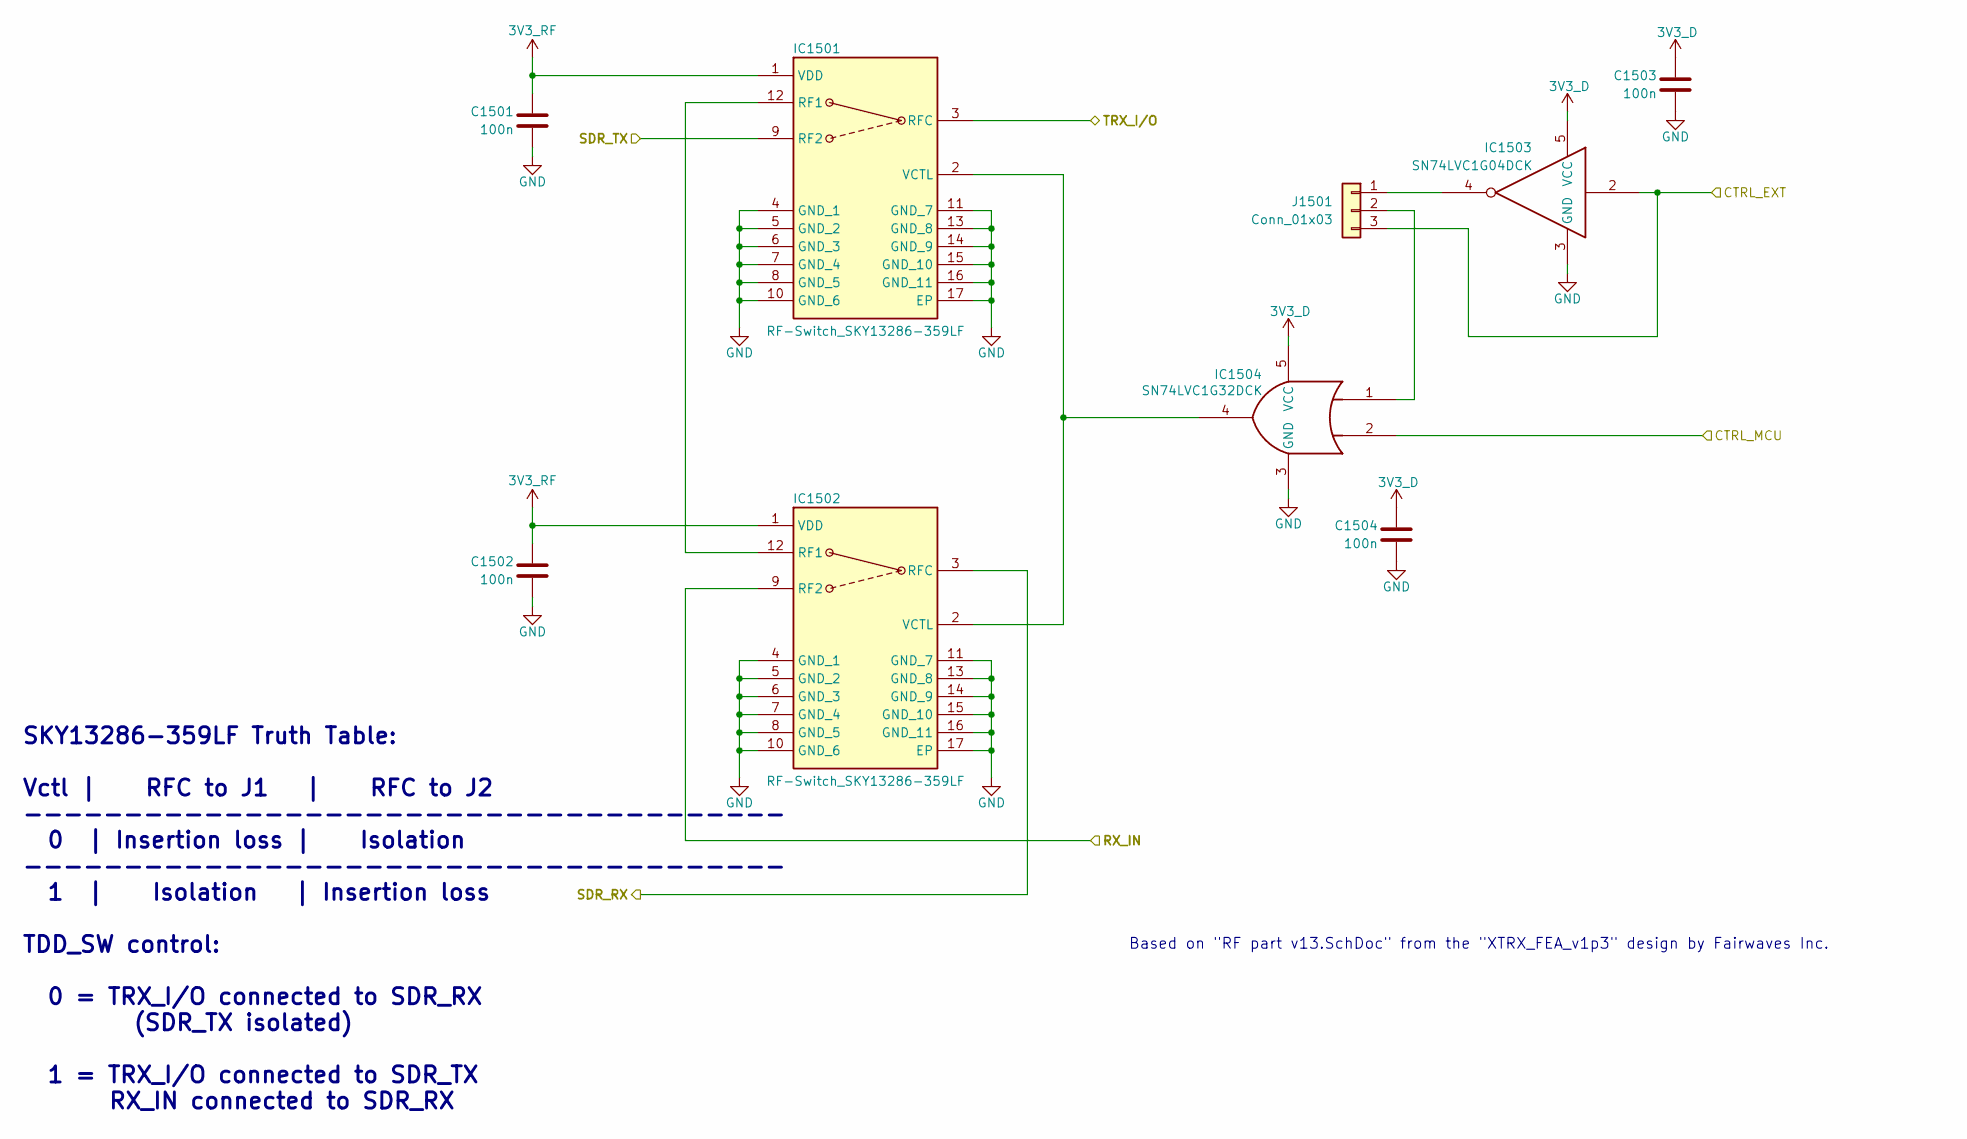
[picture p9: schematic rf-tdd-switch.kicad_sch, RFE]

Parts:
C1501, C1502, C1503, C1504: 100n; C_0402_1005Metric; JLCASSY C307331
IC1501, IC1502: RF-Switch_SKY13286-359LF; QFN65P400X400X100-17N-D; Manufacturer_Part_Number SKY13286-359LF; JLCASSY C3304168
IC1503: SN74LVC1G04DCK; SOT-353_SC-70-5; JLCASSY C8207
IC1504: SN74LVC1G32DCK; SOT-353_SC-70-5; JLCASSY C7840
J1501: Conn_01x03; PinHeader_1x03_P2.54mm_Vertical

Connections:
3V3_D: C1503.1, C1504.1, IC1503.5 (VCC), IC1504.5 (VCC); also elsewhere on the board
3V3_RF: C1501.1, C1502.1, IC1501.1 (VDD), IC1502.1 (VDD); also elsewhere on the board
/MCU/STM32_PB6: IC1504.2; also elsewhere on the board
/RF/CH_A_RX: IC1502.9 (RF2); also elsewhere on the board
/RF/CH_A_TRX: IC1501.3 (RFC); also elsewhere on the board
/RF/LNA A/RF_IN: IC1502.3 (RFC); also elsewhere on the board
/RF/PA A/RF_OUT: IC1501.9 (RF2); also elsewhere on the board
GND: C1501.2, C1502.2, C1503.2, C1504.2, IC1501.4 (GND_1), IC1501.5 (GND_2), IC1501.6 (GND_3), IC1501.7 (GND_4), IC1501.8 (GND_5), IC1501.10 (GND_6), IC1501.11 (GND_7), IC1501.13 (GND_8), IC1501.14 (GND_9), IC1501.15 (GND_10), IC1501.16 (GND_11), IC1501.17 (EP), IC1502.4 (GND_1), IC1502.5 (GND_2), IC1502.6 (GND_3), IC1502.7 (GND_4), IC1502.8 (GND_5), IC1502.10 (GND_6), IC1502.11 (GND_7), IC1502.13 (GND_8), IC1502.14 (GND_9), IC1502.15 (GND_10), IC1502.16 (GND_11), IC1502.17 (EP), IC1503.3 (GND), IC1504.3 (GND); also elsewhere on the board
unnamed: IC1501.12 (RF1), IC1502.12 (RF1)
unnamed: IC1501.2 (VCTL), IC1502.2 (VCTL), IC1504.4
unnamed: IC1503.4, J1501.1
unnamed: IC1504.1, J1501.2
TDD_A_CTRL_EXT: IC1503.2, J1501.3; also elsewhere on the board

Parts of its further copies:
C1601, C1602, C1603, C1604: 100n; C_0402_1005Metric; JLCASSY C307331
IC1601, IC1602: RF-Switch_SKY13286-359LF; QFN65P400X400X100-17N-D; Manufacturer_Part_Number SKY13286-359LF; JLCASSY C3304168
IC1603: SN74LVC1G04DCK; SOT-353_SC-70-5; JLCASSY C8207
IC1604: SN74LVC1G32DCK; SOT-353_SC-70-5; JLCASSY C7840
J1601: Conn_01x03; PinHeader_1x03_P2.54mm_Vertical

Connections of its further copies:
3V3_D: C1603.1, C1604.1, IC1603.5 (VCC), IC1604.5 (VCC); also elsewhere on the board
3V3_RF: C1601.1, C1602.1, IC1601.1 (VDD), IC1602.1 (VDD); also elsewhere on the board
/MCU/STM32_PB4: IC1604.2; also elsewhere on the board
/RF/CH_B_RX: IC1602.9 (RF2); also elsewhere on the board
/RF/CH_B_TRX: IC1601.3 (RFC); also elsewhere on the board
/RF/LNA B/RF_IN: IC1602.3 (RFC); also elsewhere on the board
/RF/PA B/RF_OUT: IC1601.9 (RF2); also elsewhere on the board
GND: C1601.2, C1602.2, C1603.2, C1604.2, IC1601.4 (GND_1), IC1601.5 (GND_2), IC1601.6 (GND_3), IC1601.7 (GND_4), IC1601.8 (GND_5), IC1601.10 (GND_6), IC1601.11 (GND_7), IC1601.13 (GND_8), IC1601.14 (GND_9), IC1601.15 (GND_10), IC1601.16 (GND_11), IC1601.17 (EP), IC1602.4 (GND_1), IC1602.5 (GND_2), IC1602.6 (GND_3), IC1602.7 (GND_4), IC1602.8 (GND_5), IC1602.10 (GND_6), IC1602.11 (GND_7), IC1602.13 (GND_8), IC1602.14 (GND_9), IC1602.15 (GND_10), IC1602.16 (GND_11), IC1602.17 (EP), IC1603.3 (GND), IC1604.3 (GND); also elsewhere on the board
unnamed: IC1601.12 (RF1), IC1602.12 (RF1)
unnamed: IC1601.2 (VCTL), IC1602.2 (VCTL), IC1604.4
unnamed: IC1603.4, J1601.1
unnamed: IC1604.1, J1601.2
TDD_B_CTRL_EXT: IC1603.2, J1601.3; also elsewhere on the board

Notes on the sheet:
Based on "RF part v13.SchDoc" from the "XTRX_FEA_v1p3" design by Fairwaves Inc.
SKY13286-359LF Truth Table: Vctl | RFC to J1 | RFC to J2 -------------------------------------- 0 | Insertion loss | Isolation -------------------------------------- 1 | Isolation | Insertion loss TDD_SW control: 0 = TRX_I/O connected to SDR_RX (SDR_TX isolated) 1 = TRX_I/O connected to SDR_TX RX_I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

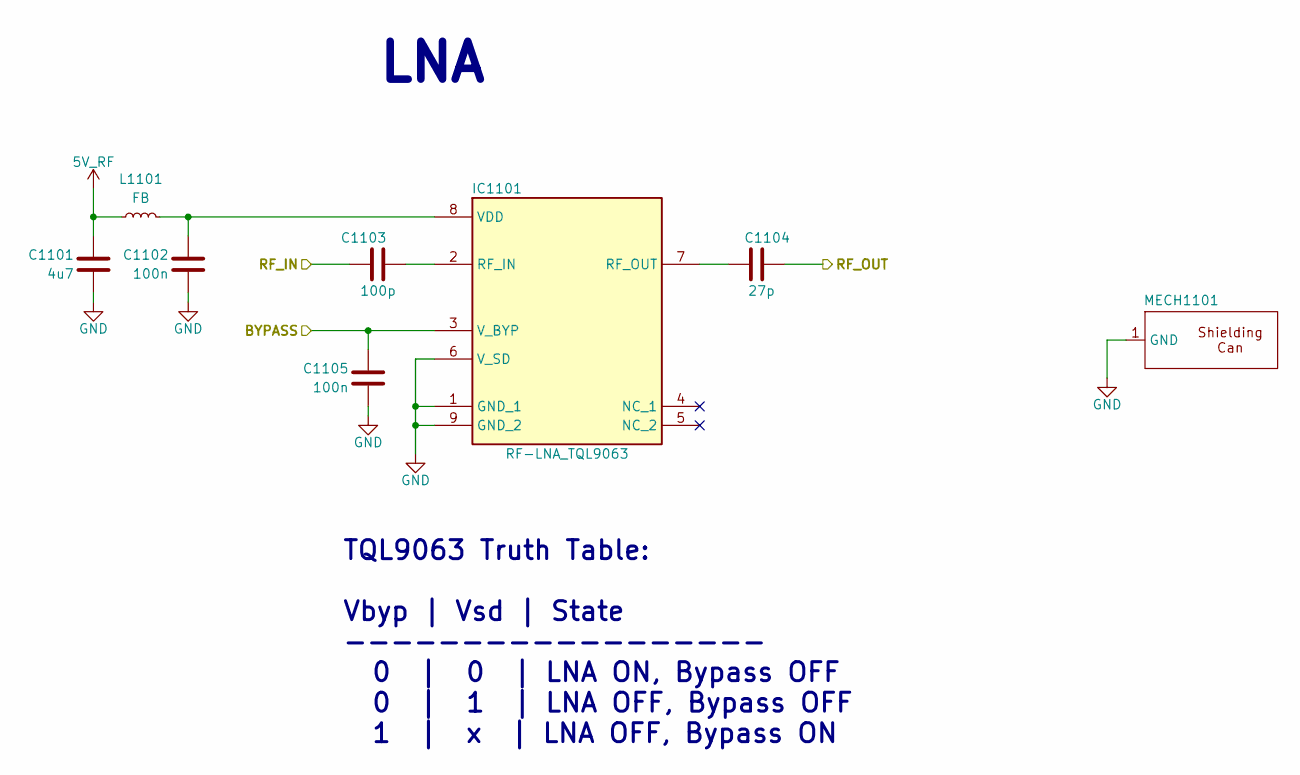
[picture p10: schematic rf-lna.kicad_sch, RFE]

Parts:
C1101: 4u7; C_0402_1005Metric; JLCASSY C23733
C1102, C1105: 100n; C_0402_1005Metric; JLCASSY C307331
C1103: 100p; C_0402_1005Metric; JLCASSY C77177
C1104: 27p; C_0402_1005Metric; JLCASSY C1557
IC1101: RF-LNA_TQL9063; SON50P200X200X90-9N; Manufacturer_Part_Number TQL9063; Mouser Part Number 772-TQL9063
L1101: FB; L_0402_1005Metric; JLCASSY C491491
MECH1101: Harwin_S03-15100300R+S0941-46R

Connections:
5V_RF: C1101.1, L1101.1; also elsewhere on the board
/MCU/STM32_PD1: C1105.1, IC1101.3 (V_BYP); also elsewhere on the board
/RF/LNA A/RF_IN: C1103.1; also elsewhere on the board
/RF/LNA A/RF_OUT: C1104.2; also elsewhere on the board
GND: C1101.2, C1102.2, C1105.2, IC1101.1 (GND_1), IC1101.6 (V_SD), IC1101.9 (GND_2), MECH1101.1 (GND); also elsewhere on the board
unnamed: C1103.2, IC1101.2 (RF_IN)
unnamed: C1104.1, IC1101.7 (RF_OUT)
unnamed: C1102.1, IC1101.8 (VDD), L1101.2

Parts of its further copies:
C1201: 4u7; C_0402_1005Metric; JLCASSY C23733
C1202, C1205: 100n; C_0402_1005Metric; JLCASSY C307331
C1203: 100p; C_0402_1005Metric; JLCASSY C77177
C1204: 27p; C_0402_1005Metric; JLCASSY C1557
IC1201: RF-LNA_TQL9063; SON50P200X200X90-9N; Manufacturer_Part_Number TQL9063; Mouser Part Number 772-TQL9063
L1201: FB; L_0402_1005Metric; JLCASSY C491491
MECH1201: Harwin_S03-15100300R+S0941-46R

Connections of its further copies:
5V_RF: C1201.1, L1201.1; also elsewhere on the board
/MCU/STM32_PA15: C1205.1, IC1201.3 (V_BYP); also elsewhere on the board
/RF/LNA B/RF_IN: C1203.1; also elsewhere on the board
/RF/LNA B/RF_OUT: C1204.2; also elsewhere on the board
GND: C1201.2, C1202.2, C1205.2, IC1201.1 (GND_1), IC1201.6 (V_SD), IC1201.9 (GND_2), MECH1201.1 (GND); also elsewhere on the board
unnamed: C1203.2, IC1201.2 (RF_IN)
unnamed: C1204.1, IC1201.7 (RF_OUT)
unnamed: C1202.1, IC1201.8 (VDD), L1201.2

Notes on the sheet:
LNA
TQL9063 Truth Table: Vbyp | Vsd | State ------------------ 0 | 0 | LNA ON, Bypass OFF 0 | 1 | LNA OFF, Bypass OFF 1 | x | LNA OFF, Bypass ON

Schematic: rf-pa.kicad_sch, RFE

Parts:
C1301: 4u7; C_0402_1005Metric; JLCASSY C23733
C1302, C1305: 100n; C_0402_1005Metric; JLCASSY C307331
C1303: 100p; C_0402_1005Metric; JLCASSY C77177
C1304: 27p; C_0402_1005Metric; JLCASSY C1557
IC1301: RF-LNA_TQL9063; SON50P200X200X90-9N; Manufacturer_Part_Number TQL9063; Mouser Part Number 772-TQL9063
L1301: FB; L_0402_1005Metric; JLCASSY C491491
MECH1301: Harwin_S03-15100300R+S0941-46R

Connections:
5V_RF: C1301.1, L1301.1; also elsewhere on the board
/MCU/STM32_PD2: C1305.1, IC1301.3 (V_BYP); also elsewhere on the board
/RF/PA A/RF_IN: C1303.1; also elsewhere on the board
/RF/PA A/RF_OUT: C1304.2; also elsewhere on the board
GND: C1301.2, C1302.2, C1305.2, IC1301.1 (GND_1), IC1301.6 (V_SD), IC1301.9 (GND_2), MECH1301.1 (GND); also elsewhere on the board
unnamed: C1303.2, IC1301.2 (RF_IN)
unnamed: C1304.1, IC1301.7 (RF_OUT)
unnamed: C1302.1, IC1301.8 (VDD), L1301.2

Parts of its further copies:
C1401: 4u7; C_0402_1005Metric; JLCASSY C23733
C1402, C1405: 100n; C_0402_1005Metric; JLCASSY C307331
C1403: 100p; C_0402_1005Metric; JLCASSY C77177
C1404: 27p; C_0402_1005Metric; JLCASSY C1557
IC1401: RF-LNA_TQL9063; SON50P200X200X90-9N; Manufacturer_Part_Number TQL9063; Mouser Part Number 772-TQL9063
L1401: FB; L_0402_1005Metric; JLCASSY C491491
MECH1401: Harwin_S03-15100300R+S0941-46R

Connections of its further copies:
5V_RF: C1401.1, L1401.1; also elsewhere on the board
/MCU/STM32_PD0: C1405.1, IC1401.3 (V_BYP); also elsewhere on the board
/RF/PA B/RF_IN: C1403.1; also elsewhere on the board
/RF/PA B/RF_OUT: C1404.2; also elsewhere on the board
GND: C1401.2, C1402.2, C1405.2, IC1401.1 (GND_1), IC1401.6 (V_SD), IC1401.9 (GND_2), MECH1401.1 (GND); also elsewhere on the board
unnamed: C1403.2, IC1401.2 (RF_IN)
unnamed: C1404.1, IC1401.7 (RF_OUT)
unnamed: C1402.1, IC1401.8 (VDD), L1401.2

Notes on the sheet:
TQL9063 Truth Table: Vbyp | Vsd | State ------------------ 0 | 0 | LNA ON, Bypass OFF 0 | 1 | LNA OFF, Bypass OFF 1 | x | LNA OFF, Bypass ON

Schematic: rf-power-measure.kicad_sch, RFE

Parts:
C902: 4u7; C_0402_1005Metric; JLCASSY C23733
C903, C904, C905, C910, C911, C912: 100n; C_0402_1005Metric; JLCASSY C307331
C906, C907: 1n; C_0402_1005Metric; JLCASSY C126493
C908: 1.8p; C_0402_1005Metric; JLCASSY C85878
C909: 10n; C_0402_1005Metric; not fitted
CON901: uFL; Molex_734120110; MPN HC-RF-IPEX0303-01; JLCASSY C2894919
IC901: RF-PwrDet_LTC5587IDD#TRPBF; SON45P300X300X80-13N-D; Manufacturer_Part_Number LTC5587IDD#TRPBF; Mouser Part Number 584-LTC5587IDD#TRPBF
IC902: Power-VRef_ADR5040BKSZ-REEL7; SOT65P210X110-3N; Manufacturer_Part_Number ADR5040BKSZ-REEL7; Mouser Part Number 584-ADR5040BKSZ-R7
IC903, IC905: RF-Switch-SPDT_SKY13286-359LF; QFN65P400X400X100-17N-D; Manufacturer_Part_Number SKY13286-359LF; JLCASSY C3304168
IC904: RF-Switch-SP3T_SKY13588-460LF; QFN50P200X200X65-13N-D; Manufacturer_Part_Number SKY13588-460LF; Mouser Part Number 873-SKY13588-460LF
L901: FB; L_0402_1005Metric; JLCASSY C491491
L902: 1.5nH; L_0402_1005Metric; JLCASSY C3911113
R901: 390; R_0402_1005Metric; JLCASSY C2906937
R1002: 68 0.1%; R_0402_1005Metric; JLCASSY C317908
TP1001: TestPoint; TestPoint_Pad_D2.0mm

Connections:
3V3_RF: C902.1, C910.1, C911.1, C912.1, IC903.1 (VDD), IC904.6 (VDD), IC905.1 (VDD), L901.1, R901.1; also elsewhere on the board
/MCU/STM32_PA5_SPI1_SCK: IC901.2 (SCK); also elsewhere on the board
/MCU/STM32_PA7_SPI1_MOSI: IC901.1 (SDO); also elsewhere on the board
/MCU/STM32_PA8: IC904.5 (V2); also elsewhere on the board
/MCU/STM32_PB0: IC901.12 (CONV); also elsewhere on the board
/MCU/STM32_PB15: IC904.4 (V1); also elsewhere on the board
/MCU/STM32_PC6: IC905.2 (VCTL); also elsewhere on the board
/MCU/STM32_PC7: IC903.2 (VCTL); also elsewhere on the board
/RF/LNA A/RF_OUT: IC905.9 (RF2); also elsewhere on the board
/RF/PA A/RF_IN: IC904.9 (J2); also elsewhere on the board
/RF/Power Measurement A/SDR_RX: IC905.3 (RFC); also elsewhere on the board
/RF/SDR_CH_A_TX: IC904.11 (RFC); also elsewhere on the board
GND: C902.2, C903.2, C904.2, C905.2, C906.2, C908.2, C909.2, C910.2, C911.2, C912.2, CON901.2 (Ext), IC901.5 (GND_1), IC901.13 (GND_2), IC902.2 (V-), IC903.4 (GND_1), IC903.5 (GND_2), IC903.6 (GND_3), IC903.7 (GND_4), IC903.8 (GND_5), IC903.10 (GND_6), IC903.11 (GND_7), IC903.13 (GND_8), IC903.14 (GND_9), IC903.15 (GND_10), IC903.16 (GND_11), IC903.17 (EP), IC904.2 (GND_1), IC904.7 (GND_2), IC904.8 (GND_3), IC904.10 (GND_4), IC904.12 (GND_5), IC904.13 (EP), IC905.4 (GND_1), IC905.5 (GND_2), IC905.6 (GND_3), IC905.7 (GND_4), IC905.8 (GND_5), IC905.10 (GND_6), IC905.11 (GND_7), IC905.13 (GND_8), IC905.14 (GND_9), IC905.15 (GND_10), IC905.16 (GND_11), IC905.17 (EP), R1002.2; also elsewhere on the board
unnamed: CON901.1 (In), IC903.12 (RF1)
unnamed: C909.1, IC901.6 (CSQ)
unnamed: C903.1, C904.1, C905.1, IC901.3 (OVDD), IC901.8 (VCC), IC901.9 (EN), IC901.11 (VDD), L901.2
unnamed: C907.2, IC901.7 (RF)
unnamed: IC901.10 (VREF), IC902.1 (V+), IC902.3 (T), R901.2
unnamed: IC903.9 (RF2), IC904.3 (J3)
unnamed: C908.1, IC903.3 (RFC), L902.1
unnamed: IC904.1 (J1), IC905.12 (RF1)

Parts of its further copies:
C1002: 4u7; C_0402_1005Metric; JLCASSY C23733
C1003, C1004, C1005, C1010, C1011, C1012: 100n; C_0402_1005Metric; JLCASSY C307331
C1006, C1007: 1n; C_0402_1005Metric; JLCASSY C126493
C1008: 1.8p; C_0402_1005Metric; JLCASSY C85878
C1009: 10n; C_0402_1005Metric; not fitted
CON1001: uFL; Molex_734120110; MPN HC-RF-IPEX0303-01; JLCASSY C2894919
IC1001: RF-PwrDet_LTC5587IDD#TRPBF; SON45P300X300X80-13N-D; Manufacturer_Part_Number LTC5587IDD#TRPBF; Mouser Part Number 584-LTC5587IDD#TRPBF
IC1002: Power-VRef_ADR5040BKSZ-REEL7; SOT65P210X110-3N; Manufacturer_Part_Number ADR5040BKSZ-REEL7; Mouser Part Number 584-ADR5040BKSZ-R7
IC1003, IC1005: RF-Switch-SPDT_SKY13286-359LF; QFN65P400X400X100-17N-D; Manufacturer_Part_Number SKY13286-359LF; JLCASSY C3304168
IC1004: RF-Switch-SP3T_SKY13588-460LF; QFN50P200X200X65-13N-D; Manufacturer_Part_Number SKY13588-460LF; Mouser Part Number 873-SKY13588-460LF
L1001: FB; L_0402_1005Metric; JLCASSY C491491
L1002: 1.5nH; L_0402_1005Metric; JLCASSY C3911113
R902: 68 0.1%; R_0402_1005Metric; JLCASSY C317908
R1001: 390; R_0402_1005Metric; JLCASSY C2906937
TP901: TestPoint; TestPoint_Pad_D2.0mm

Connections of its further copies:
3V3_RF: C1002.1, C1010.1, C1011.1, C1012.1, IC1003.1 (VDD), IC1004.6 (VDD), IC1005.1 (VDD), L1001.1, R1001.1; also elsewhere on the board
/MCU/STM32_PA0_SPI2_SCK: IC1001.2 (SCK); also elsewhere on the board
/MCU/STM32_PA4_SPI2_MOSI: IC1001.1 (SDO); also elsewhere on the board
/MCU/STM32_PA6: IC1001.12 (CONV); also elsewhere on the board
/MCU/STM32_PB11: IC1004.4 (V1); also elsewhere on the board
/MCU/STM32_PB12: IC1004.5 (V2); also elsewhere on the board
/MCU/STM32_PB13: IC1005.2 (VCTL); also elsewhere on the board
/MCU/STM32_PB14: IC1003.2 (VCTL); also elsewhere on the board
/RF/LNA B/RF_OUT: IC1005.9 (RF2); also elsewhere on the board
/RF/PA B/RF_IN: IC1004.9 (J2); also elsewhere on the board
/RF/Power Measurement B/SDR_RX: IC1005.3 (RFC); also elsewhere on the board
/RF/SDR_CH_B_TX: IC1004.11 (RFC); also elsewhere on the board
GND: C1002.2, C1003.2, C1004.2, C1005.2, C1006.2, C1008.2, C1009.2, C1010.2, C1011.2, C1012.2, CON1001.2 (Ext), IC1001.5 (GND_1), IC1001.13 (GND_2), IC1002.2 (V-), IC1003.4 (GND_1), IC1003.5 (GND_2), IC1003.6 (GND_3), IC1003.7 (GND_4), IC1003.8 (GND_5), IC1003.10 (GND_6), IC1003.11 (GND_7), IC1003.13 (GND_8), IC1003.14 (GND_9), IC1003.15 (GND_10), IC1003.16 (GND_11), IC1003.17 (EP), IC1004.2 (GND_1), IC1004.7 (GND_2), IC1004.8 (GND_3), IC1004.10 (GND_4), IC1004.12 (GND_5), IC1004.13 (EP), IC1005.4 (GND_1), IC1005.5 (GND_2), IC1005.6 (GND_3), IC1005.7 (GND_4), IC1005.8 (GND_5), IC1005.10 (GND_6), IC1005.11 (GND_7), IC1005.13 (GND_8), IC1005.14 (GND_9), IC1005.15 (GND_10), IC1005.16 (GND_11), IC1005.17 (EP), R902.2; also elsewhere on the board
unnamed: CON1001.1 (In), IC1003.12 (RF1)
unnamed: C1009.1, IC1001.6 (CSQ)
unnamed: C1003.1, C1004.1, C1005.1, IC1001.3 (OVDD), IC1001.8 (VCC), IC1001.9 (EN), IC1001.11 (VDD), L1001.2
unnamed: C1007.2, IC1001.7 (RF)
unnamed: IC1001.10 (VREF), IC1002.1 (V+), IC1002.3 (T), R1001.2
unnamed: IC1003.9 (RF2), IC1004.3 (J3)
unnamed: C1008.1, IC1003.3 (RFC), L1002.1
unnamed: IC1004.1 (J1), IC1005.12 (RF1)

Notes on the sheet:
RFin match for freq. range: 1.75 to 2.2GHz See pg.12 in datasheet for details
2.048V ±0.1 Voltage Reference
- OVdd: ADC Output Driver Supply - Vcc: Detector Power Supply - Vref: ADC Reference Input Voltage - Vdd: ADC Power Supply

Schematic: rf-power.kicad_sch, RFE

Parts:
C601: 22u; C_1206_3216Metric; JLCASSY C478862
C602, C604: 100n; C_0402_1005Metric; JLCASSY C307331
C603: 4u7; C_0402_1005Metric; JLCASSY C23733
IC601: Power-LDO_NCP59800BMNADJTBG; DFN-8(3x3); Manufacturer_Part_Number NCP59800BMNADJTBG; Mouser Part Number 863-NCP59800BMNADJTB
L601: FB; L_0402_1005Metric; JLCASSY C491491
R601: 30K9; R_0402_1005Metric; JLCASSY C852715
R602: 10K; R_0402_1005Metric; JLCASSY C2902636

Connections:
3V3_RF: C603.1, IC601.1 (OUT_1), IC601.2 (OUT_2), R601.1; also elsewhere on the board
5V_RF: C602.1, IC601.5 (EN), IC601.7 (IN_1), IC601.8 (IN_2), L601.2; also elsewhere on the board
GND: C601.2, C602.2, C603.2, C604.2, IC601.4 (GND), IC601.EP, R602.2; also elsewhere on the board
unnamed: IC601.3 (FB/SNS), R601.2, R602.1
unnamed: C604.1, IC601.6 (NR)
VUSB: C601.1, L601.1; also elsewhere on the board

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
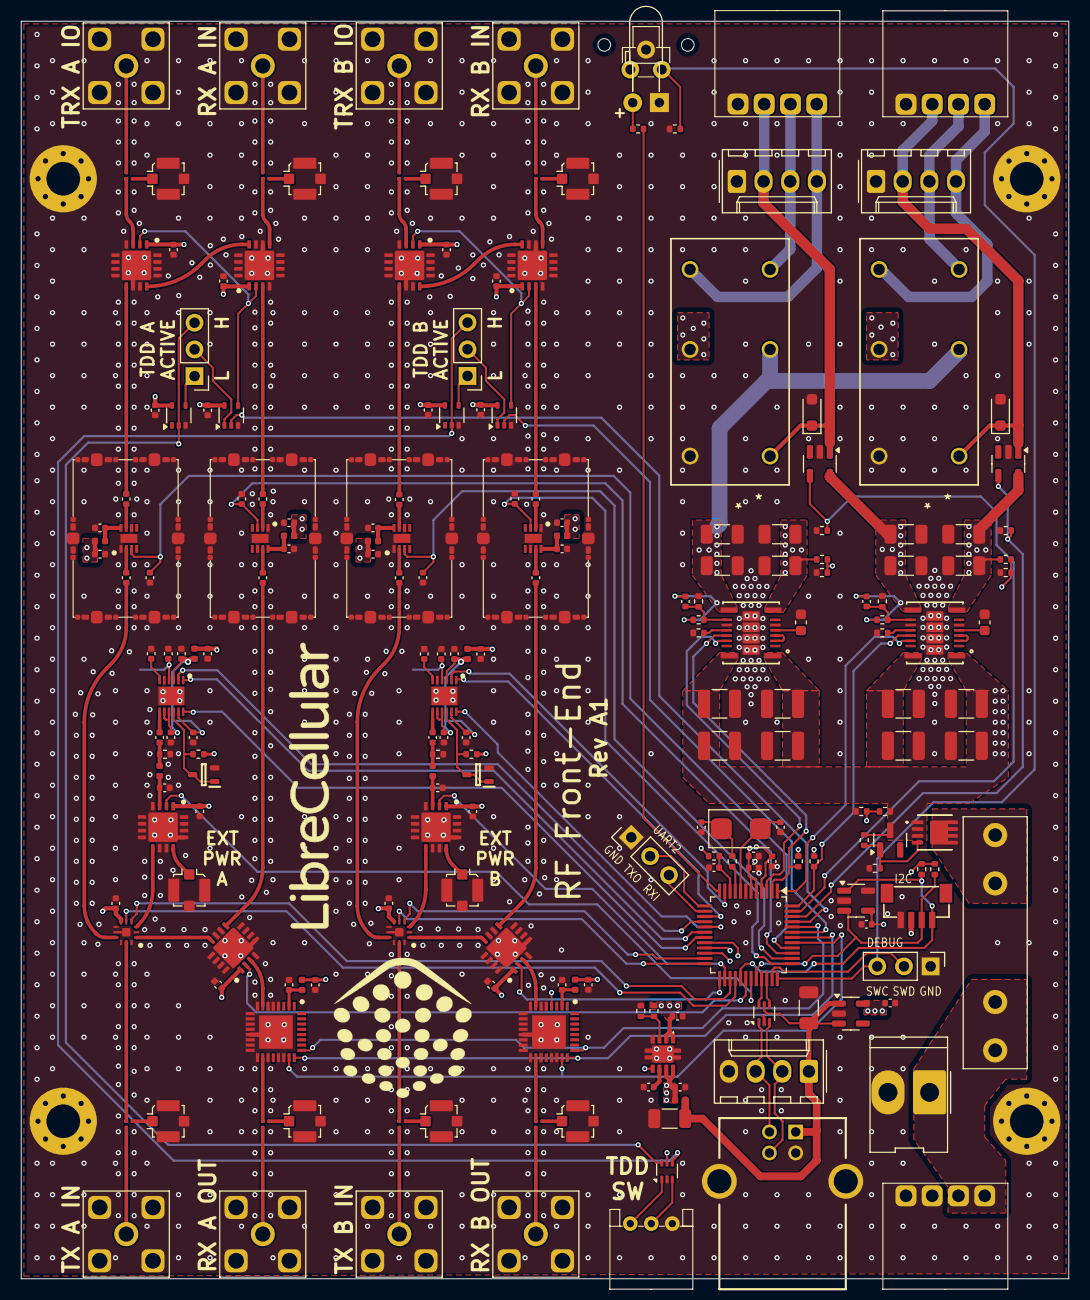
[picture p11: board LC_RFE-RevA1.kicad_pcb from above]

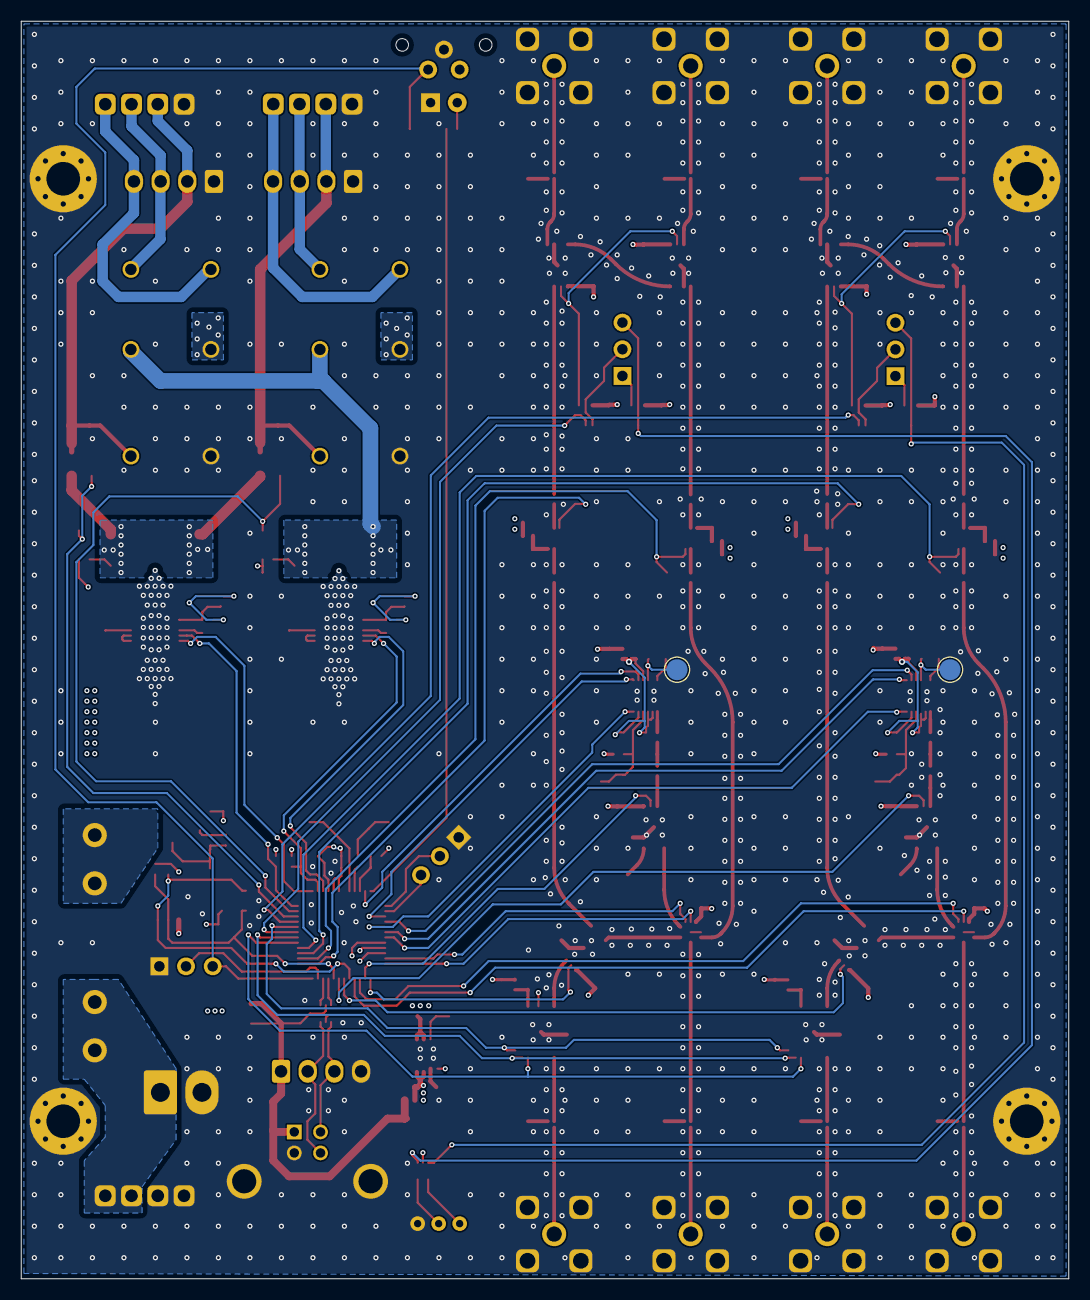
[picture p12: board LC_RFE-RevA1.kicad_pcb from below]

Board: 4 copper layers, 99.8 x 119.8 mm, 231 parts (2 on the bottom side), 155 nets.

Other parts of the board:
Ref**: Val**; LibreCellular_Logo

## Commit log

2024-07-11 initial release for libs, panels and RevA1
    [LC_RFE-RevA1-BOM.xlsx, LC_RFE-RevA1.kicad_pcb, LC_RFE-RevA1.kicad_sch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]
2025-05-10 RevA1 schematic cleanup
2025-05-10 RevA2 initial commit
    [LC_RFE-RevA2-BOM-ForSMA.xlsx, LC_RFE-RevA2-BOM-ForUFL.xlsx, LC_RFE-RevA2.kicad_sch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]
